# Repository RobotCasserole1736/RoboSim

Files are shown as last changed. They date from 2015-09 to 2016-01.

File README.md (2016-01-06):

# RoboSim
Arduino-based hardware-in-the-loop simulation of FRC robot hardware.

## Purpose
RoboSim is a set of hardware and software designed to enable simulation of 
mechanical hardware on a robot designed for the First Robotics Competition. 
The goal is to enable mentors and students to design a sufficiently functional plant mode for their robot, 
connect a fully-constructed electrical board with software, and observe the effects of control inputs on 
their simulated robot platform. This allows the electrical, software, and mechanical teams to work more in parallel.

## High level design.
RoboSim is build around an Arduino Mega. There are two sets of peripheral boards which 
expand the arduino's IO capability. The Arduino sends state information to a desktop PC 
running a plant model, and receives return data which it can feed back to the simulated 
robot's electrical board. The plant model on the PC is run using GNU Octave (a free Malab 
alternative). The Octave Plant model simulates the robot hardware (taking only motor and 
solenoid voltages as inputs). Serial data is transfered between the arduino and Octave for 
IO with the electrical board.

## Project Status
RoboSim is currently in development. All releases as of now are tested, but considered "alpha". 

## Screen-shots
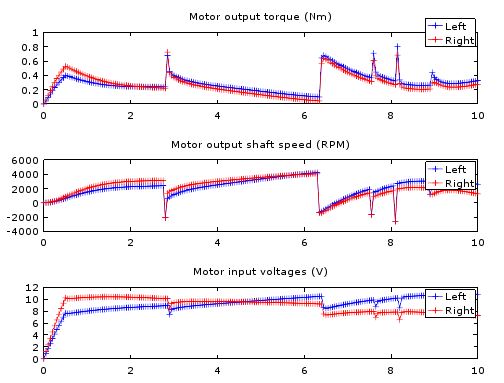
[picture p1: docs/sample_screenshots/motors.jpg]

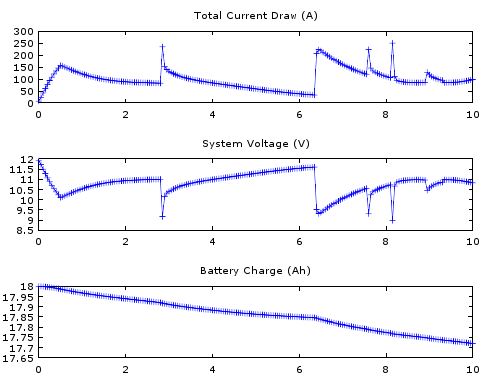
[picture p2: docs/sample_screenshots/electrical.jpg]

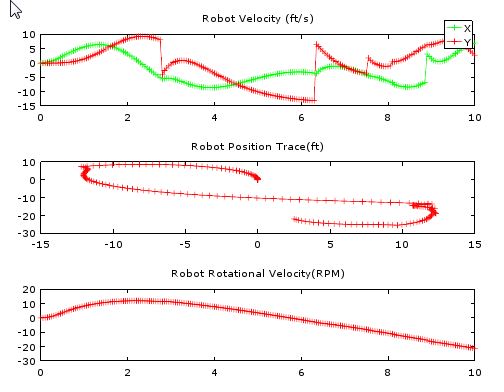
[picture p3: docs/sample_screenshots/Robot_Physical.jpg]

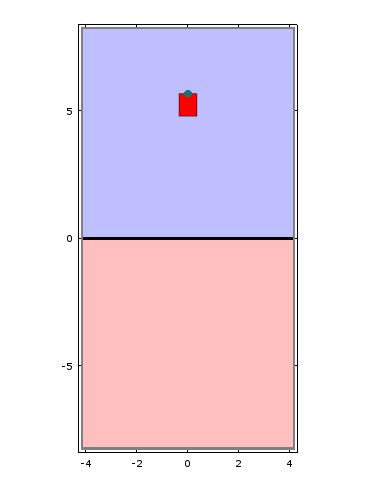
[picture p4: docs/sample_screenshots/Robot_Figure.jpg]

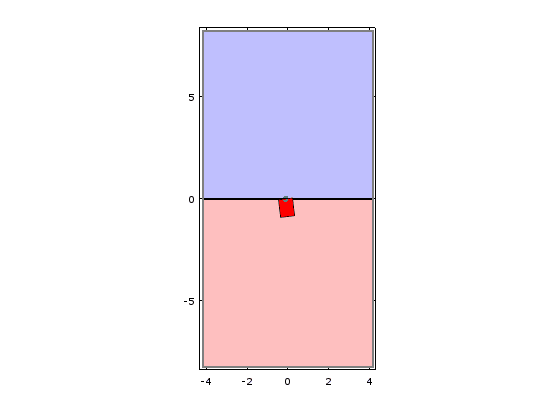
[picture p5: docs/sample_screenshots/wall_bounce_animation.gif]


## Repository Contents
- arduino_src - source code for the embedded arduino controller inside of RoboSim
- Octave - source code for the Octave-run plant model and GUI
- Eagle - electrical schematics for RoboSim peripheral boards
- PSPICE - electrical simulations for RoboSim peripheral boards
- docs - an increasing collection of documentation.

## Required software:
- Arduino IDE
  - https://www.arduino.cc/en/Main/Software
- Python 3.2 (32bit)- other versions may work but are untested
  - https://www.python.org/download/releases/3.2.5/
- PySerial 2.7 win32 py3k
  -https://pypi.python.org/pypi/pyserial
- GNU Octave + instrument-control package
  - http://www.gnu.org/software/octave/download.html
  - Once installed, run "pkg install -forge instrument-control" at the Octave command window
- Other Tools
  - Eagle PCB design
    - http://www.cadsoftusa.com/download-eagle/
  - LtSpice circuit simulator
    - http://www.linear.com/designtools/software/
  - Autodesk Inventor

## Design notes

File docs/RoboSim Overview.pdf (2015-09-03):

# RoboSim

### FRC Team 1736 Robot Casserole

## Overview

### - What:

- A flexible platform to simulate FRC robot hardware components
- A tool to increase development speed, test coverage, code and electrical robustness
- A platform for teaching concepts such as Plant Models, Design-For-Test, C coding, Digital Logic, Analog-Digital conversion, low-level embedded coding.

## Overview

### - Why

- Historically, electrical and software validation has been slowed due to lack of hardware to use for test ■ Mistakes can also be costly as mechanical components are damaged by errors in SW or wiring.
■ Mass permutation and regression testing is not feasible
■ Importance of testing has not been addressed.

## Overview

### - How

- Core real-time plant model running on Arduino Uno ■ Modularized SW for stable HW interface code with easy-to-modify plant model
- Visualization through connected PC
■ Python-based GUI
- Custom-built interface electronics to replicate CIM motors, encoders, analog sensors, limit switches, etc.

## Design Philosophy

### - Simulate Motors, Mechanical linkages & mechanisms, and sensor feedback only

- Input is voltage from motor controllers, output is simulated response of sensors and visualization
- Agnostic to electronics hardware technology
- Zero intrusion into electrical or SW design
- 100% of SW which impacts control can be tested

## Software Technologies Involved

### - Arduino

- Embedded C & C++

### - Python - Git

### - Future potential for Matlab/Simulink or Dynasty integration

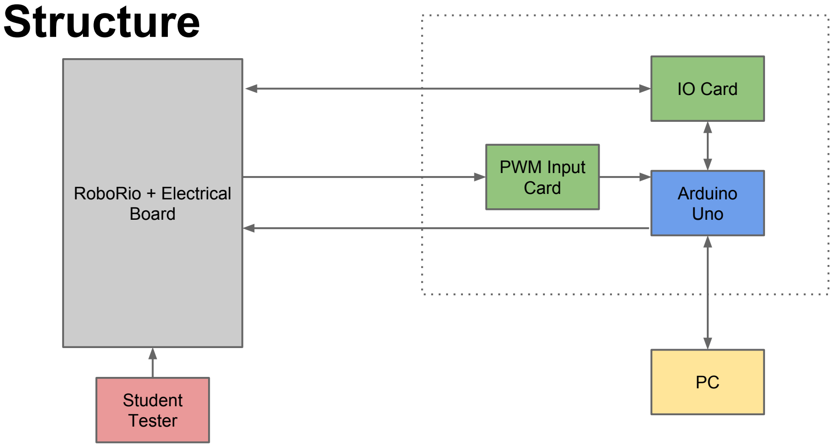
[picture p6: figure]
Structure; Arduino Uno; PWM Input Card; IO Card; RoboRio + Electrical Board; Student Tester

## Initial Spec for IO Capabilities

- 6 Motor Inputs (analog)
- Filtered by PWM Card, read by Arduino
- 8 Solenoid Inputs (digital)
- Read by IO card
- 8 Limit Switch Outputs (digital)
- Produced by IO Card
- 2 Analog Sensor Outputs
- R-R2 ladder DAC on IO Card, 0-5V
- 4 Quadrature Encoder Outputs
- Emulated in SW by Arduino

## Initial Spec for SW Capabilities

- 100ms Main plant model loop
- Processor load metric generated
- Serial port broadcast of state
- User defined update rate and message contents
- Interrupt-based emulation of Encoders onboard
- Isolated HW interfacing and Plant model code
- Plant custom to year, while HW interfacing stays constant

## IO Board

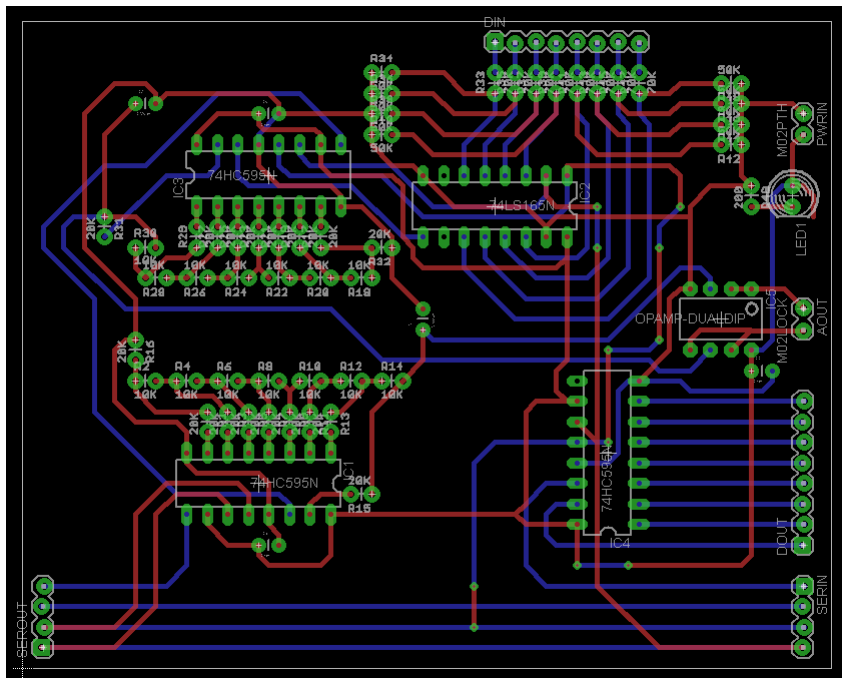
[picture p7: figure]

## IO Board - Description

### - Eight Digital Inputs - Eight Digital Outputs - Two Analog Outputs - Serial/Clock/Sync interface with Arduino - Can stack an arbitrary number of boards to increase IO

## PWM Input Card

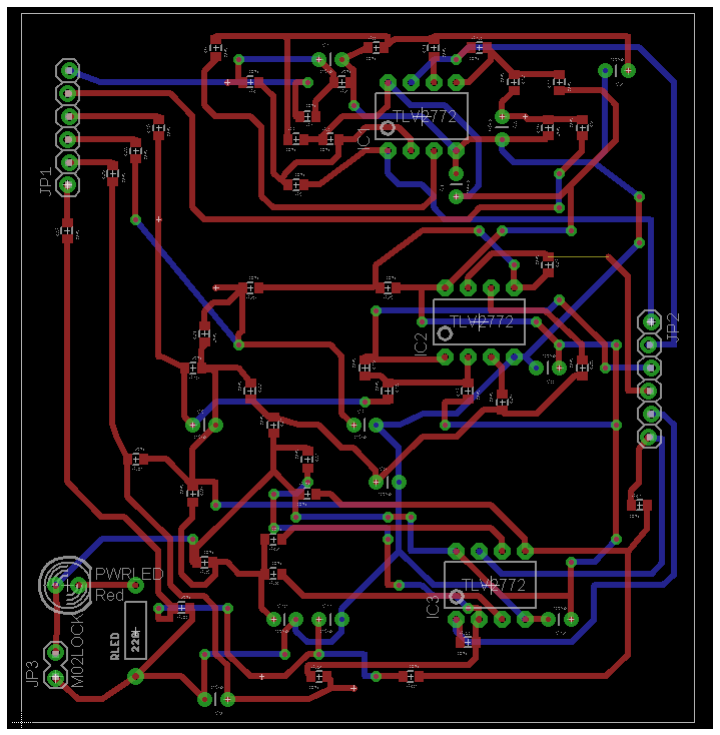
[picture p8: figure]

## PWM Input Card - Description

### - Six Low-Pass Filter and Offset Units - Converts PWM output from any Motor Controller into 0-5V signal readable by Arduino Analog Inputs - One card for Arduino Uno

## PWM Input Card - pSpice Simulation

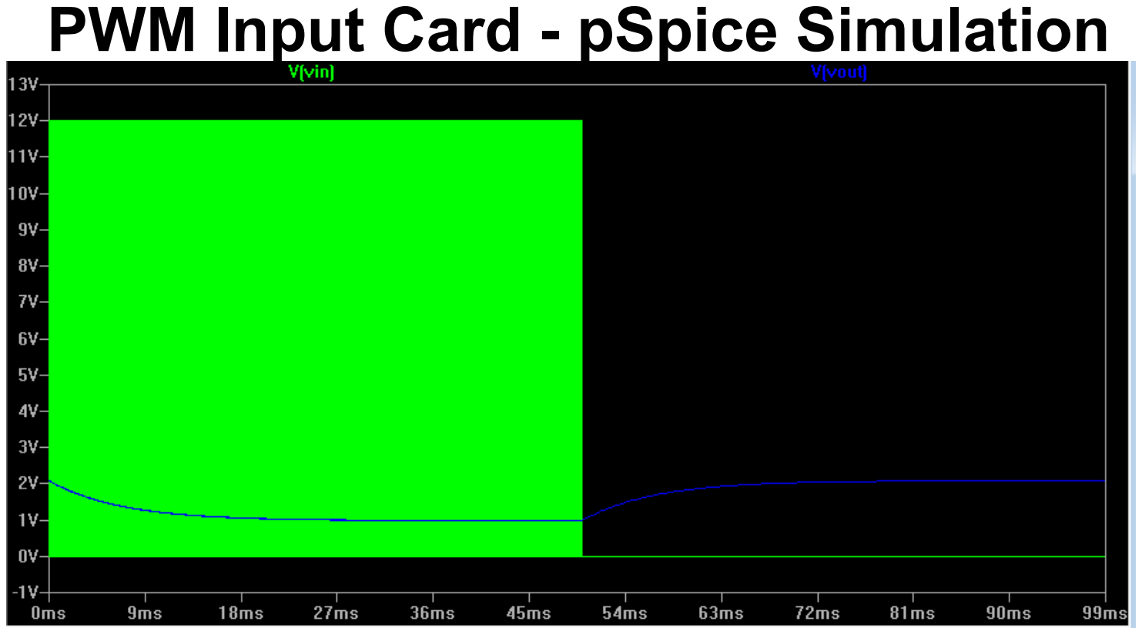
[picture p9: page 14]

## PWM Input Card - pSpice Simulation

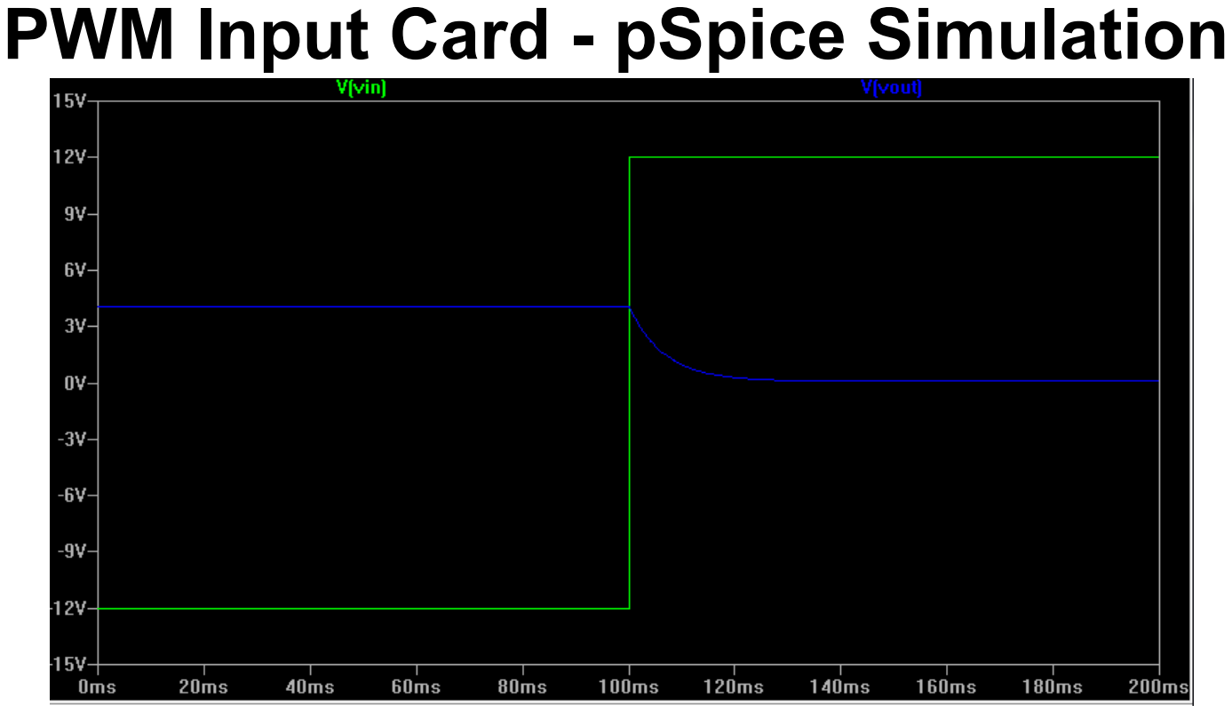
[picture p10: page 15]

## Quadrature Encoder Emulation

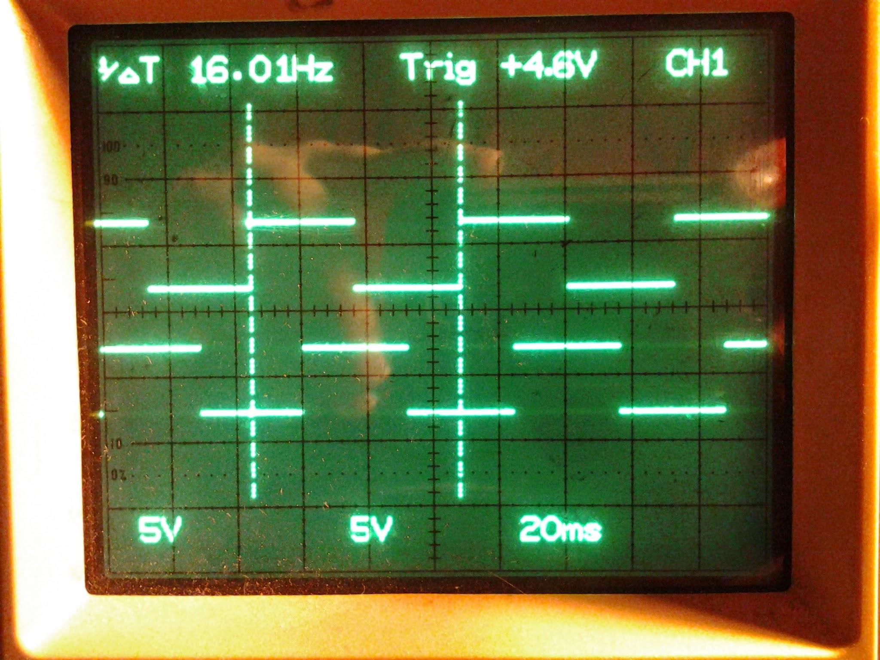
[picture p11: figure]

## Initial Cost Estimates

### - Arduino Uno - $30.00 New

- Can use existing

### - 1 IO Card + 1 PWM Card = $58.68

- No spare parts included in cost
- Can possibly source some parts from Cat B-Stock

## Community

### - Prototype source code is already available

- https://github.com/RobotCasserole1736/RoboSim

### - All designs will be open source

- Software (Arduino and PC)
- Hardware (Schematics, BOM, PCB designs)
- Documentation

## Future Expandability

- Design and validate plant models in Matlab, run generated code on Arduino
- Use larger Arduino with more Analog or Digital IO
- Controllable electronic loads to simulate motors in various operating conditions
- GPIB control of power supply to simulate battery voltage fluctuation with load
- Hardware-based Encoder Emulation
- More-robust electrical fault protection
- Automated regression testing routines

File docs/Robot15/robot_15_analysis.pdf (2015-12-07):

# RoboSim Sample Robot Plant Model Calculations

Chris Gerth - FRC 1736 Robot Casserole

Fall 2015

Abstract

An analysis of a simple tank-drive robot is presented. The simple plant model is designed to be a starting point for year-to-year development of more detailed robot models. The device modeled has two sets of motors to drive motion in a tank-drive fashion, along with a normal battery and electrical system.

## Contents

I | Background Academics Primer | 4
1 Calculus | 4
2 Trigonometry | 7
3 Physics | 7
II | Component Models | 14
4 Electric Motor | 14
5 Main Battery | 17
6 Main Circuit Breaker | 18
7 Compressor and Tank | 18
8 Traction Wheel | 19
III | Integrated Model | 20
9 Electrical Subsystem | 20

10 Drivetrain Subsystem | 20
11 Pneumatic subsystem | 23
12 Field Collision Model | 23
IV | Design Notes | 24
13 Software Architecture | 24
14 RoboSim Hardware | 26

## Part I

# Background Academics Primer

In this section, we will seek to demonstrate the “basic” math and physics required to understand RoboSim. This content is effectively a whirlwind summary of the important parts of AP Calc BC, AP Physics C, basic Chemistry, and any introductory Electronics course.

## 1 Calculus

Sir Isaac Newton was a smart man. He came up with calculus. Either him or Leibniz. In any event. Calculus is a particular field of study within mathematics. It studies functions and properties of functions.

### 1.1 Functions

A function can be thought of as a box which takes one input, and produces some outputs based on that input. For RoboSim, we will deal with many functions of time. This is to say that we will look at how properties change over time. The “Box” in this case is the robot itself. The most fundamental input to the robot is time. As time progresses forward, different properties of the robot change. These properties include things like location, speed, torque, rotation, electrical current draw, etc. In a mathematical sense, time is the input, and the various properties are the output. At every given time, each property has a value. Additionally, the physics of the configuration of the parts of the robot determine relationships between the quantities as time progresses forward. For example, a large voltage applied to motors will induce larger torques and speeds and current draws.

### 1.2 Continuous Functions, Derivatives and Integrals

Continuous calculus is what is usually studied in High School. It is assumed that time is linear and continuous. Valid times are t = 0s, t = 1.2429543987s, t = 3.25s, etc. Any value of time is a defined. An infinitely detailed timeline can be established.
Calculus looks at two primary things about functions: Derivatives and Integrals.
A Derivative of a function describes how quickly the function is changing as time goes on. On a curve on a Cartesian (x/y) plot, the derivative is the same as the slope of the curve at any given point, as shown in Figure 1.

x = y(t)

x =

dy
dt
An Integral of a function describes how big or small the function’s value has been historically. On a Cartesian plot, the integral is the same as the area between the curve and the x axis over a given period of time, as shown in Figure 2.

x = y(t)

X =

ˆ
y(t)dt + c

For the purposes of RoboSim, there is no need to discuss the calculation of integrals or derivatives in the continuous domain.
If a function is getting larger quickly, its derivative will be big at that time. If it is getting smaller in a hurry, its derivative will be negative
If a function has been big for a long time, its integral will be large. If it’s been bouncing around but equally above and below zero, the integral will be very small.

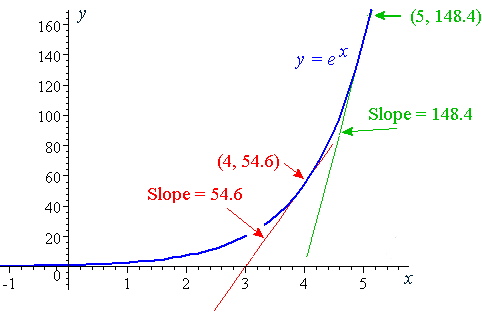
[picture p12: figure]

Figure 1: Illustration of a derivative as the “instantaneous slope” of a curve

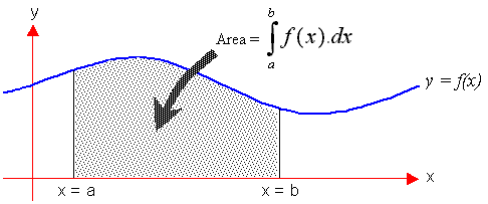
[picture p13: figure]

Figure 2: Illustration of a integral as the “area under a curve”

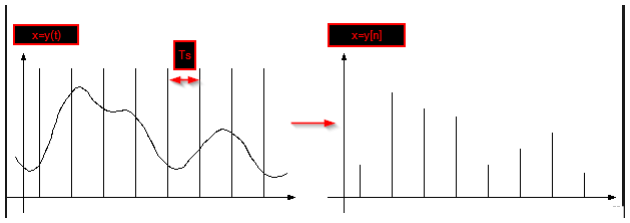
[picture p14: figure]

Figure 3: Sampling a continuous function x=y(t) to produce discrete function x=y[n]

### 1.3 Discrete Functions, Derivatives and Integrals

Discrete functions are very similar to normal functions, except they are only defined at certain, regularly-repeating time values. In this way, a discrete function could be though of as a set of time, value pairs.

{0.00, 3}, {0.01, 2}, {0.02, 1}, {0.03, 0}, ...

We might turn a continuous function into a discrete one by sampling it at regular intervals. This is usually the way that sensors and digital systems are integrated - the sensor reads an analog value continuously, and the digital system records the sensor’s value at specific points in time.
We usually notate a discrete time function as such

x = y[n]

For a function y that produces a value x at time index n. For all discrete functions, we must always specify a “Sample Time” (notated T s) to indicate the spacing between samples. For RoboSim, T s is hard-coded to 50ms. Note the square brackets which indicate discrete time. Here n is an index, not a measure in seconds. Multiplying the n index by the sample time T s yields the actual (real-world) time in seconds.
In Discrete time calculus, we define derivatives as follows:

x = y[n]

dx
dt

∼=

y[n] − y[n − 1]
T s
This formula says “A function’s derivative is equal to the current value minus the previous value, scaled by the sample time.” You may recognize this form from part of the “Limit” definition of a derivative. Note here that if we force Ts to zero, we have a continuous derivative. However, because computer systems cannot sample infinitely fast, we accept a small but finite Ts as a very close approximation. The conditions under which this approximation is acceptable is the subject of Nyquist Frequency theory, but is a topic out of scope for this discussion.
In Discrete time calculus, we define Integrals as follows:

x = y[n]
ˆ
xdt ∼=

Xn

i=0

y[i] ∗ T s

This equation says “A function’s integral is equal to the sum of all previous values, scaled by the sample time”.You may recognize this from the Riemann sum approximation of an integral. If we force Ts to zero, we end up with a continuous integral. But again, since computer systems cannot sample infinitely fast, we accept a small but finite Ts and move on with our lives.

## 2 Trigonometry

You are likely already aware of most trig concepts. sin(), cos(), tan()are among some of the functions you should be familiar with. For the purposes of calculations of robosim, we will do all angle calculations in radians. Additionally, we will use to atan2() function, which is very similar to the inverse tangent (atan()). However, it has some extra definitions to give it a full output range of [0, 2π]for any given X/Y inputs. You can look up more details online, but the formal definition is as follows:

atan2(X, Y ) =

atan −Y
X
X > 0
180◦ + atan
Y
X
Y ≥ 0, X < 0
−180◦ + atan
Y
X
Y < 0, X < 0
90◦ | Y > 0, X = 0
−90◦ | Y < 0, X = 0
undef ined | Y = 0, X = 0

## 3 Physics

Physics is also a thing that Newton did. Told you he was smart. In this section, we will begin to analyze the constraints imposed by mother nature between different quantities on our robot.

### 3.1 Position, Linear Motion, and Calculus

For physics to work, we must have objects in places. The place the object is at is called its Position. Let us define the following function which describes an object’s location along one axis at any time. Specifically, it says how far the object is from an arbitrary zero point at any time:

Distance = x[n]
Velocity is how fast an object is moving. Velocity can be positive or negative. Positive velocity means the distance gets bigger, and negative velocity means the distance gets smaller. Because of physics, velocity is therefore the derivative of distance.
V elocity = v[n]

v[n] = dx
dt =

x[n] − x[n − 1]
T s
Acceleration is how fast an object is changing in velocity. Acceleration can be positive or negative. A positive acceleration means the object is going faster and faster and faster. A negative acceleration means the object is slowing down. Because physics is still physics, acceleration is the derivative of velocity.

Acceleration = a[n]

a[n] = dv
dt =

v[n] − v[n − 1]
T s
Note that integration allows you to go the other way. That is to say, velocity is the integral of acceleration, and distance is the integral of velocity.

v[n] =Xn

i=0

a[i] ∗ T s

x[n] =Xn

i=0

v[i] ∗ T s

Plots of these relationships are shown in Figure 4.
For units, we will always use metric. Therefore, distance is in meters (m), velocity is in meters per second (m/s), and acceleration is in meters per second, per second (m/sˆ2)

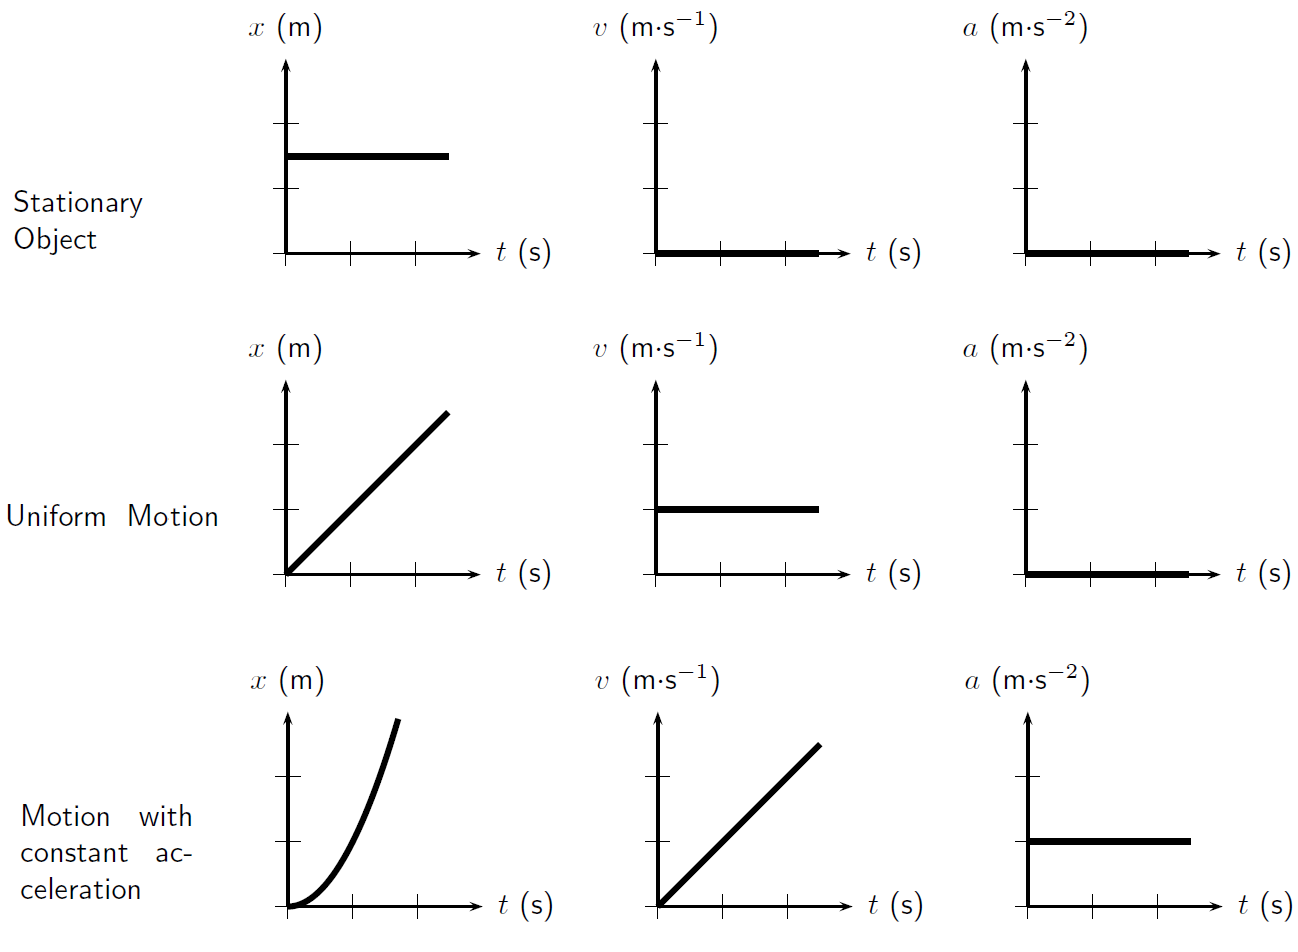
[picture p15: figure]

Figure 4: Examples of motion, relating acceleration, velocity, and position

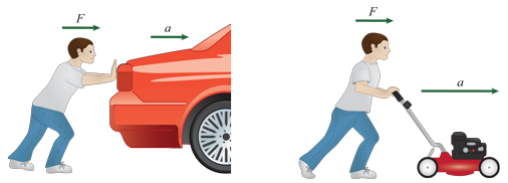
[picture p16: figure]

Figure 5: Newton’s Second Law

### 3.2 Forces and Linear motion

### 3.2.1 Newton’s Law

Force is something pushing on another thing. The more you push, the faster and faster you will go. The larger the object, the harder it is to make it go faster.
Newton’s laws of motion allow us to define the following: At any given time, Acceleration is proportional to Force, scaled by an objects mass:

F orce = mass ∗ acceleration

F[n] = m ∗ a[n]

Note that Force is measured in Newtons (N), mass is measured in kilograms (kg), and acceleration is in meters per second per second (m/sˆ2).
Note also that force changes over time, and acceleration changes over time, but we assume mass is constant.

### 3.2.2 Sources of Forces

Forces come from many places. A student pushing on a robot frame is one possible, simple source. A turning wheel in contact with the floor is another. Meshed gear teeth pushing on one another is yet another transfer of force. Of the list mentioned so far, friction is very important and has some special calculations associated with it.

### 3.2.3 Frictional Forces

Friction is a force which opposes two contacting surfaces from sliding relative to each other. It comes from microscopic interactions of matter in contact with each other. It can get very complex and is not fully understood, but can be well modeled at a macro level. We will discuss this model, as it is the most useful for FRC robotics applications. There are two main types of friction: Static and Kinetic.

### 3.2.4 Static Friction

Static friction deals with the case where two surfaces are not moving relative to one another. If you were to pin a book in place on a wall by only pressing on the book toward the wall, you would be using the static friction between the book and the wall to oppose the force of gravity, keeping the book from falling. This is illustrated in Figure 6. Static frictional force will take on whatever value it needs to to counter out other forces, up to a certain point. This certain point is called the maximum static frictional force. It is calculated with the following formula:

FSmax[n] = µS ∗ FN [n]

Here, FSmax is the maximum static frictional force. It always points in the opposite direction as any force acting along the same axis. FN is the “normal” force, or the force pinning the two surfaces together. µS is the Coefficient of Static Friction, which is derived from how effective the two surfaces are at sticking to each-other. Two smooth,

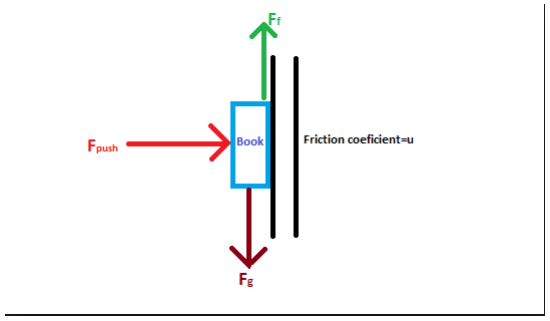
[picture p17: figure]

Figure 6: Static friction pinning a book to a wall

slick surfaces (like two pieces of smooth hard plastic) will have a small µS, while two rough surfaces (like concrete) will have a large µS. Usually, µS is just looked up in a table.
Static friction is often informally called “Stiction” in the engineering world, since it causes things to stick together. Also, “Stiction” is a portmanteau of “Static Friction”. Engineers are a clever bunch.

### 3.2.5 Kinetic Friction

Kinetic friction deals with the case where two surfaces are sliding relative to each other. If you were to slide a book along the ground, the force that opposes your efforts to push the book is the kinetic frictional force of the book in contact with the ground. It is calculated by this formula:

FK[n] = µK ∗ FN [n]

Again, FKis the kinetic frictional force. It always points in the opposite direction of motion of the interface (opposes the motion occurring). FN is still the “normal” force, or the force pinning the two surfaces together. µK is the coefficient of kinetic friction, which again determines how effective the materials can interface with each other to produce an opposing force.
For most materials, µK is slightly than µS.
Note that as a wheel is rotating with the ground, there is no relative motion between the ground and the point of contact with the wheel. Indeed, the motion of the robot is due to the rotation of the wheel, and not due to the wheel slipping over the ground. A non-slipping robot’s wheel-ground interface lies in the Static Friction domain. When wheel-ground interfaces start to enter the Kinetic friction domain, the effect is what many young people refer to as “drifting”.

### 3.3 Torque and Rotation

Because symmetry is a thing of life, Newton’s laws of motion also have analogs for rotational motion.
Instead of force, we now have Torque. Torque is force that goes in a circle. It is measured in Newton-meters. All torque acts about a central pivot point. This may be the center of mass of the robot, the center of a gear, the center of a shaft, the center of a wheel, etc.
As indicated by the unit, a torque always has two important things to consider - How much force is pushing in a circle, and how far from the center of the circle is that force acting?
The distance from the central pivot point of the rotation to the point of application of force is called the “Lever Arm” of the torque. Bigger lever arms mean more torque for the same force.
This is why wrenches have long handles. They are designed to turn things in a circle with some amount of torque. Assuming a human can only exert a maximum amount of force, a longer handle makes for a longer lever arm, which in turn means a higher max torque applied. If a bolt is stuck, one option is a bigger wrench with a longer handle.

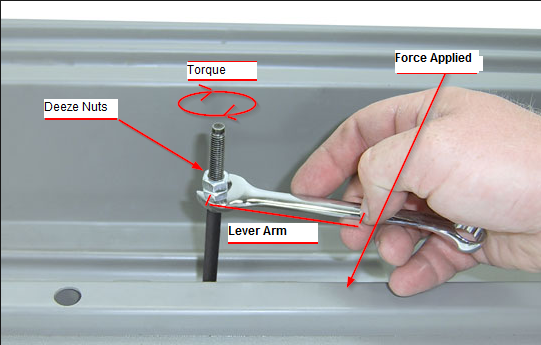
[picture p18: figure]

Figure 7: Torque exerted on a nut

### 3.3.1 Rotational Motion Parameters

There are rotational measurements which are analogous to the linear motion parameters discussed above. Lower-case Greek letters are used to describe these rotational parameters
The current angle a rotating object is pointed in is referred to as theta:

Angle = θ[n]

The rate at which that angle is changing is rotational velocity, or omega:

RotationalV elocity = ω[n]

The rate of change of the rotational velocity is the rotational acceleration, or alpha:

RotationalAcceleration = α[n]

As with linear motion, velocity is the derivative of position, and acceleration is the derivative of velocity.

ω[n] = dθ
dt =

θ[n] − θ[n − 1]
T s

α[n] = dω
dt =

ω[n] − ω[n − 1]
T s
Also as with linear motion, velocity is the integral of acceleration, and position is the integral of velocity.

ω[n] =Xn

i=0

α[i] ∗ T s

θ[n] =Xn

i=0

ω[i] ∗ T s

### 3.3.2 Torque and Rotational motion

The relationship between torque and rotational motion is highly analogous to force and linear motion:
At any given time, an object’s rotational acceleration is proportional to the torque applied to it, scaled by the object’s “moment of inertia”.

torque = moment of inertia ∗ rotational acceleration

T[n] = I ∗ α[n]

An object’s “moment of inertia” is like its total mass, but also accounts for how far that mass is from the center of rotation. The more mass an object has, and the further that mass is from the center of rotation, the harder it is to get the object rotating at a different speed. The actual value of this is in units of kilogram meters-squared (kg mˆ2), and is most easily calculated with a table of shapes and corresponding formulas.
Although we have assumed the moment of inertia to be constant, that is not always the case. Although it is rare for a robot to add or loose mass during a match, it is more common for the location of that mass to change on the robot. For example, if an arm extends out by a foot from the robot, the location of the mass of that arm is now further from the center. This increases the robot’s moment of inertia, which makes it harder for the drive-train to start or stop the robot from spinning.

### 3.4 Ideal Gas Law

Cylinders, tanks, compressors, and valves are all pneumatic components used on FRC robots. Pneumatic components on a robot all deal with the movement of compressed air, and the transfer of energy involved therein. Air is the gas used within these systems. Under the normal temperatures experienced in the robot, and the 125psi pressure restriction of FRC rules, air acts much like an ideal gas. Therefore, it is appropriate to model it with the ideal gas law:

P V = nrT

Here, P refers to the pressure of the gas (in kilo-pascals, or kPa), V refers to the volume of gas considered (in Liters, or L), T refers to the temperature of the gas (in kelvin, or K), and n refers to the number of moles of gas molecules being considered. The remaining symbol r is the “Gas Constant”, a constant with units L*kPa/(K*mol), and is numerically equal to 8.3144621. It is determined by the physics of interacting gas particles. Its derivation will not be described in this paper
Note also that n is in moles. A “mole” is a unit-less multiplier, like “dozen”. For example, if I have a dozen donuts, it means I have twelve donuts. Similarly, if I have a mole of donuts, I have 6.022 ∗ 10²³donuts. 1 The reason for its use here is that gas molecules are tiny, and usually we have a lot of them. It’s a lot simpler to do math talking about “1 mole of molecules” rather than absurdly large numbers.
What the ideal gas law describes is the relationship between pressure, temperature, amount of gas, the volume the gas occupies. For example, when a compressor kicks on, it forces more moles of air into the same volume. We also assume that temperature does not change. Therefore, based on the above equation, if T, r, and V are unchanged, and n increases, then P must also increase to keep the equation balanced. This makes since, since anyone who was observed a properly-set-up pneumatic system knows turning on the compressor makes system pressure go up.

### 3.5 Electrical Laws

Motors, motor controllers, batteries, wires, and circuit breakers are all part of the electrical system on a robot. These components obey many laws related to electricity.

### 3.5.1 Electrical Introduction

For FRC robotics purposes, electricity is the movement of electrons through “conductors”. A conductor is any substance which has freely-moving charged particles, most commonly electrons. Usually these movements are random, but when they start to go in the same direction, we say there is an “electric current” present. Metals are the most common conductors.
The opposite of a conductor is an insulator. Common insulators include glass, wood, and plastic. These substances to not have freely-moving charged particles, so they cannot sustain an electric current. By wrapping a

1

Interestingly enough, the average jelly donuts contains 10⁶ Joules of energy. This means that one mole of jelly donuts would have about 6 ∗ 10²⁹Joules of energy. The rotational energy stored in Earth’s rotation is about 2 ∗ 10²⁹Joules. This means that if you had a 100% efficient rocket powered by jelly donuts, and attached it to the earth’s equator, you could stop the earth from spinning, and still have 2/3rds of your donuts left over for eating! The more you know...

conductor inside an insulator, you create an isolated conduit to move electrical current in an organized fashion (eg, a wire).

### 3.5.2 Basic Electrical Quantities and Relationships

When talking about the flow of electrons, there are two important quantities.
Current is the number of electrons flowing past a given point over a given time. It is usually indicated by the lower-case letter i (blame the French). Units are almost always in “Amperes” or “Amps” for short. The Amp unit is denoted “A”. One amp of current is equal to 6.24 ∗ 10¹⁸electrons passing a given point on a wire in one second.

Current = i[n]

Voltage is the “force” which causes the motion of electrons in a conductor. The more voltage, the more of a punch the electrons will have. It is measured in a unit called “Volts” and denoted with the letter “V”.

V oltage = v[n]

Note that the word “force” is used very loosely here, as the energy associated with electricity has much more to do with electric and magnetic fields, and not so much the physical impact of tiny electrons on a mass. However, the details of this theory is beyond the scope of this paper.
Resistance is how easily a substance allows electricity to pass through. Conductors have a very low resistance, while insulators have a very high resistance. Resistance to electrical flow can be affected by many factors, including the temperature and physical shape of the device. Resistance is measured in a unit called an “Ohm”, and is denoted with a capital Greek letter Omega (Ω).
The resistance of a device determines how much voltage it pushes back with (ie, the “voltage drop”) when a current runs through it. This relationship is linear, and is expressed with Ohm’s Law:

v[n] = R ∗ i[n]

This equation states that for a given amount of current running through a device, that device will push back on that flow with a proportional amount of voltage, scaled by the device’s resistance.
For example, Ohm’s law explains why system voltage drops when you drive a robot very hard. All batteries have some small amount of internal resistance (something like 0.012Ω). They usually supply around 12V of voltage. However, as motors and solenoids and compressors draw large amounts of current, the battery internally starts to fight itself due to its internal resistance. The voltage actually supplied by the battery is then some quantity less than 12V, and the amount of drop is roughly proportional to the amount of current pulled from the battery. Inductance and Capacitance are properties of devices, describing their ability to store electrical energy and release it over time. The math associated with these is beyond the scope of this paper.
Power is not specifically an electrical topic, but relates strongly to electrical quantities. Electrical Power refers to the total energy absorbed or dissipated by an electrical component over time. Positive power in an electrical component implies energy is leaving the system (via motion, heat, sound, etc.), while negative power means energy is entering the system (Battery, power supply, hand-cranked generator, etc.)
Power is calculated in many ways. In general, it can be found my multiplying voltage and current:

P[n] = v[n] ∗ i[n]

Power will be measured in units of Watts (denoted “W”).

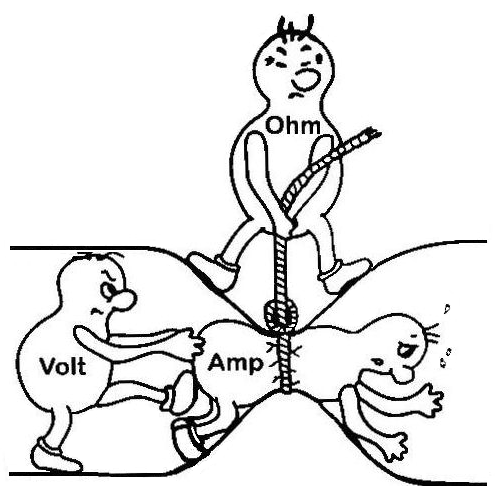
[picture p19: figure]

Figure 8: Ohm’s Law, with various electrical quantities models as anthropomorphic peanuts.

## Part II

# Component Models

## 4 Electric Motor

Simply put, an electric motor is a device which converts electrical energy into rotational mechanical energy. Current flowing through the motor causes a force on the motor. However, the interactions of the motor’s electrical and mechanical parts also drives a variety of equilibrium points. Due to the level of interaction, an electric motor is one of the more complex devices to model. It helps to split the motor into two portions, the electrical and the mechanical parts.

### 4.1 Electrical Model

A motor, electrically speaking, is a two-terminal device. For a DC motor,its interior windings and communicator will be modeled as a resistor, inductor, and voltage source in series. The resistance and inductance model the physical configuration of the windings inside the motor. The wire itself is always non-deal, having some resistance. Additionally, since the wire is wrapped in tight coils, there is some non-negligible inductance.
The voltage source models what is referred to as “Back EMF”. Remember that a changing magnetic field inside coils of wire will induce a voltage in those wires (this is how electrical generators work). Although at first it is the energy input to the motor that causes the shaft to start to spin, as the shaft spins it generates its own set of magnetic fields. This secondary field begins to induce a new voltage in the coils called Back EMF. This voltage’s value is linearly proportional to the speed the motor is turning at. This is why a free-wheeling motor has a maximum speed.
All these parts of the electrical model create voltages to oppose or aid the flow of current through the motor. At the end of the day, the torque produced by the motor is linearly proportional to the current flowing through

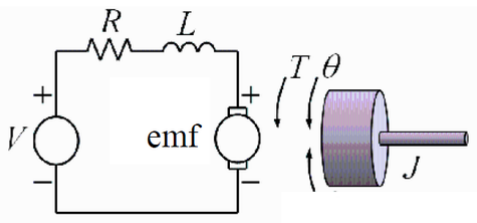
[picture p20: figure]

Figure 9: A combined motor electrical and mechanical model

it.
To illustrate, follow this example concerning a free-wheeling motor (no load torque): The motor is stopped, and a voltage is suddenly applied to it. Little current flows at first due to the inductance. However, as time goes on, the magnetic field builds up and more and more current flows. As current begins to flow in ever increasing quantities, more and more torque is applied to the output shaft. The output shaft begins to accelerate due to the torque. As the output shaft picks up speed, the back EMF voltage also increases. Soon, it is no longer the inductance that is limiting current flow, but instead the back EMF voltage source. Eventually, an equilibrium is hit where there is (theoretically) no current flow through the motor anymore, as the back EMF voltage completely counters out the supply voltage.
In reality, there is always a small current draw due to the load torques from friction in the internal bearings (and various other reasons).
Given a supply voltage and a back EMF, applying KVL around the motor circuit in Figure 9, we deduce the following continuous-time equation for the motor current:

Vin(t) = Im(t)Rm + Lm

dIm
dt + Vemf (t)

Here, Vinis the supply voltage to the motor, Rmand Lm are the motor’s winding’s resistance and inductance (in Ohms and Henries), and Vemf is the Back EMF voltage from any rotation of the output shaft. The Lm

dIm
dt term
comes from the voltage-current relationship in an inductor. Simply put, an inductor produces a large voltage in response to large changes in current (hence, the derivative term). The derivation of this relationship is beyond the scope of this document.
Moving to the discrete domain, we find the following equation:

Vin[n] = Im[n]Rm + Lm

Im[n] − Im[n − 1]
T s |
+ Vemf [n]

We now solve for Im[n], the motor current at the present time-step:

Im[n] = 1
Rm +

Lm
T s
LmIm[n − 1]
T s

− Vemf [n] + Vin[n]

### 4.2 Joining of Electrical and Mechanical Models

Now, we shall introduce some constants to link the mechanical and electrical models together.²
These can be derived from analyzing the physical construction of the motor, but are usually empirically measured. The Torque Constant Kt determines the relationship between Torque and Current. We define the following linking equation:

2Data for this section can be found in the CIM motor curves available from Andymark: http://files.andymark.com/CIM-motor-curve-am-0255.pdf

Tm[n] = Kt ∗ Im[n]

Tmis the torque produced on the output shaft of the motor.Kt is measured in units of Torque per Current, or Nm/A
It is known that at zero current, zero torque is present (hence, no need for any constant offset in the above equation). Kt is most easily calculated from a motor’s Stall Torque and Stall Current, two figures readily available for most motors.

Kt =

Tstall

Istall
In the case of a CIM motor, the stall torque is 2.429 Nm, and the stall current is 131.227 A.
The Speed Constant Kidetermines the relationship between the magnitude of the Back EMF voltage, and the rotational speed of the output shaft. We define the following linking equation:

Vemf [n] = Ki ∗ ωm[n]

ωmis the rotational speed of the output shaft of the motor. Ki

is measured in units of Voltage per Rotational Velocity, or V/(rad/s).
It is again known that at zero speed, there is zero back EMF. Ki

is most easily calculated by analyzing the motor in its “free-wheeling” speed, where a positive voltage Vsupply has been applied to the motor, and a maximum speed has been observed sustained at the output shaft (ωFW ). Assuming the input current in this state (IFW ) is also known, the following relationship is true:

Ki =

Vsupply − IFW ∗ Rm

ωFW
Be sure to add scaling constants for units as needed - Current is often reported in mA (not A), and free-wheel speeds in RPM (not rad/s).
Substituting these Electrical/Mechanical constant relationships in and re-arranging terms, we arrive at the final equation used in the motor model:

Tm[n] = Tm[n − 1] + Ts ∗

Kt
Lm
Vin[n] −

Tm[n − 1]Rm
Kt

− Ki ∗ ωm[n − 1]

Im[n] = Tm[n]
Kt
We have now reduced the motor to a model which takes a voltage, speed, and previous torque as input, and determines what the new torque value should be. Additionally, via the second equation, we can determine the current draw of the given motor.

### 4.3 Integration with Larger Systems

The one remaining relationship unexplored is the speed-torque relationship in the motor. Thus far we have defined the motor which produces some torque, dependent upon the voltage applied and the speed the motor runs at. However, once this torque is applied, how quickly does the speed change? This question can only be answered by analyzing what the motor is hooked up to. In the case of a free-wheeling motor, not attached to anything, the answer lies in the moment of inertia of the shaft itself, and the rotational friction in the bearings. When driving an actual robot, the torque of the motor is transferred through the drive-train to the ground. The wheels convert the torque to a linear force, and start rotating in response to the net acceleration of the robot. This rotational speed is then transferred back up through the drive-train to the motors. In all cases, friction provides a constant drag on motion. The exact math in determining the torque-speed relationship must be derived from the device attached to the motor, not the motor itself.

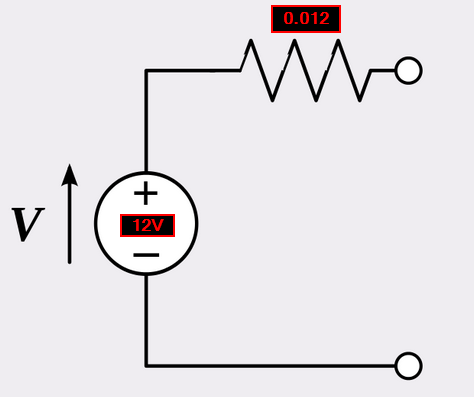
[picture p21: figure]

Figure 10: A non-idea voltage source, modeling a battery

## 5 Main Battery

There are many sources of power for electrical circuits. While analyzing circuits, the most common source used is what is referred to as a “Ideal Voltage Source”. This is a device which produces a voltage across its terminals, and that voltage does not change with the amount of current flowing through the device. In theory, such a device could provide an infinite amount of power (keep voltage the same as current increases indefinitely). This assumption makes analysis of circuits easier, but fails to provide the whole picture.

### 5.1 Modeling Voltage Drop due to Instantaneous Current Draw

A battery is what is referred to as a “Non-ideal Voltage Source”. It can be modeled with an ideal voltage source in series with a resistor. The voltage source models the current-pushing potential of the chemical reaction in the battery, and the resistor models the internal parasitic resistance which causes voltage to drop as more current is drawn. The MK ES17-12 batteries standard for FRC³ have an average internal resistance of 0.012Ω. The nominal (no-current-draw) voltage of the battery can be anywhere from 13V down to 8V or even lower, depending on how much the battery is charged.
For the purposes of RoboSim, we have not yet modeled the decaying nominal voltage of the battery as it discharges, since the simulation is not designed to be accurate for long-term endurance tests. However, we have modeled the drop in supply voltage with elevated current draw. See Figure 10 for the circuit model employed. In general, the output of the battery model is the system voltage, and the input is the total current draw from the battery. The model is governed by the following equation:

Vsys[n] = Vnom[n] − Rbat ∗ Idraw[n]

Vsysis the robot system voltage at a given sample time n. Vnom[n]is the nominal (no-current-draw) voltage of the battery. For simplicity it may be assumed to be 12V, but could also be calculated based on the remaining charge in the battery. Rbatis the parasitic internal resistance of the battery, assumed equals to 0.012Ω for the ES17-12. Finally, Idrawis the total current demand of the robot at sample time n. Within the plant model, the total current draw is calculated by summing the current draw from each motor, solenoid, compressor, etc., along with nominal background current draw (such as electronics, lights, or fans).

3Constants derived from data-sheet at http://www.mkbattery.com/images/ES17-12.pdf

### 5.2 Modeling Total Remaining Charge based on Aggregate Current Draw

Additionally, the battery model usesIdrawto calculate the total charge remaining in the battery. This charge-remaining metric could be used to drop nominal battery voltage over time, but will also give developers indication of the amount of battery life drained by performing certain maneuvers with their robot. The battery is designed to have 17 Amp-Hours of charge in it. This means that you can pull 17 amps for one hour, one amp for 17 hours, or any other combination of amps and hours which, when multiplied, gets you to 17. We model battery charge by calculating the number of Amp-Hours drained from the battery by the current draw every plant loop. This behavior is defined by the equation:

Q[n] = Q[n − 1] −

Idraw[n] ∗ T s
3600
Q[n] is the present charge (in amp-hours) in the battery, and Q[n−1] is what the charge was last loop. Here, we always calculate the present charge by subtracting the current draw (in amps), multiplied by the sample time (with a 3600 factor to convert Ts from seconds to hours). This charge metric can be used to analyze expected battery life of a given robot design.

## 6 Main Circuit Breaker

## 7 Compressor and Tank

The compressor and tank library model reporesent the source of pneumatic energy for the robot. The compressor modeled is the Viair 90C, standard for FRC robots. The air tanks have an adjustable volume (set by defining the number of half-liter tanks).

7.1 “The System”

For all pneumatic calculations, the volume inside the tanks, tubing, valves, etc. is modeled collectively as the “system”. In principle, there are a certain number of air molecules inside of this system at all time. The model track the number of moles of air inside the system, and then can calculate the pressure using the total volume and an assumed temperature. The compressor as a device adds moles of air to this system, while any leaks or cylinder actuations reduce the number of moles in the system.
The system requires a “reset” trigger at the start of the simulation. When reset, it triggers calculations to determine nominal (ie, one-atmosphere) quantities of air molecules in the system. This initalizes the state variable to the right number of moles of air for an assumed temperature.
The temperature of air in the system is assumed to always be at 70◦F. This is based on the idea that the compressor does not induce much extra heat into the air it compresses, and any extra heat is dissapated to the atmosphere through the compressor metal body, tank walls, and tubing. Making this assumption allows us to not have to calculate the thermal equations relating heat loss through a complex system of many different materials of different shapes.

### 7.2 Compressor

Viair provides performance data for its compressors. For the 90C model, there is a non-linear relationship between flow rate, pressure, and drawn current. At any given time, the compressor must fight the system pressure to put more air into the system. Additionally, the faster the flow rate and the higher the system pressure, the more current is needed to keep pushing moles of air into the system. The numerical values can be found in the compressor’s datasheet, and are plotted with interpolation in Figure 11.
Note that the performance data is listed in imperial units, so some conversion factors are applied in software to get to the metric equivilants.
Every simulation loop, a total number of new moles of air to be added to the system is calculated based on this performance data, and whether the compressor is running or not. By using the ideal gas law, and assuming the system pressure is known, the number of new moles of air can be calculated:

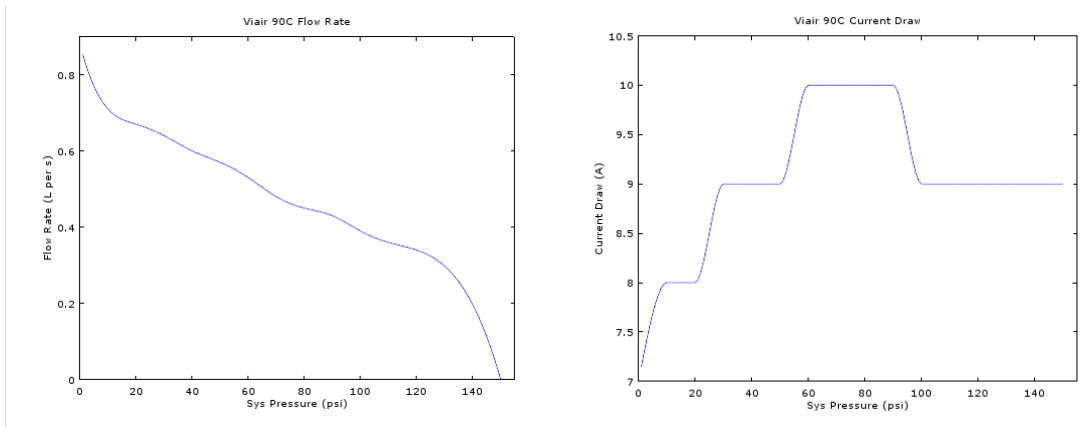
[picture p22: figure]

Figure 11: Viair 90C Performance Data

4num moles comp[n] = P[n − 1]F[n] ∗ T s rT
For P being the previous system pressure, F being the volumetric flow rate (calculated from performance data if compressor is running, or 0 if not running),T s being the sample time, T being the system air temperature (assumed equal to70◦F), and r = 8.31 being the gas constant in units of L∗kP a
K∗mol.
Finally, given the current system pressure and running/not-running state of the compressor, the current draw at timestep n may also be calculated.

## 8 Traction Wheel

## Part III

# Integrated Model

There are multiple parts to the robot model. Each shall be discussed in detail here.

## 9 Electrical Subsystem

The electrical subsytem consists of the robot’s power source (the main battery), all current drawing devices (motors, solenoids, compressors, etc.), and any safety devices (main circut breaker, etc.).
One of the key metrics to track is total current draw from the battery. As soon as we know the compressor state and motor torques, we calculate total current draw with the following equation:

Idraw[n] = (IMR[n] + IML[n]) ∗ NM + Icomp[n] + Inom

Here, IMLand IMRare the current draw from the left and right motor respectively. Icompis the air compressor current, which is assumed 0 until the pneumatic system is implemented. Finally, Inomrepresents background, nominal current draw from the roboRIO, LED’s, fans, etc. We have modeled it as a constan 0.5A current draw. System voltage is the voltage supplied by the battery to all of the robot components. Usually it is near 12V, but large current draws or weak batteries may decrease it. This Idrawis used to calculate the present system voltage via the equations laid out in section 5. Additionally, the main battery charge is tracked via the equation presesnted in that same section. Idrawis also used by the main circuit breaker model to determine if the breaker should be in a tripped or closed state. If tripped, system voltage is driven to zero. See section 6 for more details on this component.
Once the system voltage is known, it can be used to calculate adjusted motor voltages driving the motors. There is feedback here: as motors push harder, they draw more current, which drops the system voltage. In turn, this prevents the motors from outputting their maximum power. This systsem-voltage-drop relationship is maintained by treating the voltage input waveform (whether from the RoboSim hardware measurements or from test vectors in a fully-simulated setup) as “voltage commands”. The actual voltage going to each motor is calculated off of this equation

VM[n] = Vsys[n]
12

∗ Vcmd[n]

Where Vcmdis the commanded voltage to the motor, Vsysis the robot system voltage, and VMis the voltage actually applied to the motor.

## 10 Drivetrain Subsystem

The drivetriain consists of the components which exert forces on the net robot body, and move it around the field. Conceptually, it transforms torque from the motors, and calculates what forces those torques exert on the robot. Then, an acceleration, velocity, and position of the robot body can be calculated from these forces. Rotation is also accounted for. Finally, the net motion of the robot is transformed back into a speed, which is fed back up through the drivetrain to determine what rotational speed the motors are running at.
For Robot 15, a simple tank drive is modeled. The Drivetrain consists of two sets of drive wheels/motors/gearboxes
- a left and a right set. Each set of drive equpment has a given gear ratio, wheel diameter, and number of drive motors. It is assumed that each drive equipment set can exert a force toward the front or the back of the robot, and that force is applied at a point offset to the leftt or right of the robot’s physical center. The distance from the center to the point of force application is called the “Motor Width”
The robot additionally has a width and height (the half-width and half-height are shown, and are used in the software for calculations). The X and Y axes are also provided. Note that all linear velocity components are assumed relative to reference frame fixed on the field, not on the robot (unless otherwise indicated)
The first step in the calcualtions for the drivetrain are to calculate all the forces acting on the robot.

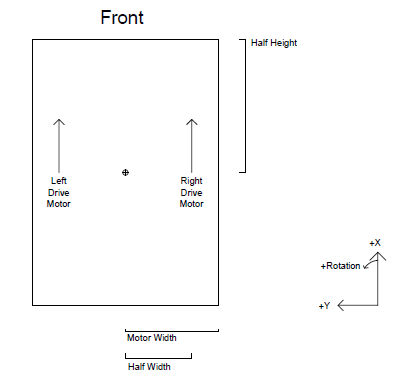
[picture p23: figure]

Figure 12: The model of the tank drive robot. Note that MotorWidth and HalfWidth are mixed up, this should be changed.

### 10.1 Linear Force from Drivetrain Motors

The torque from the motor is a function of the motor’s speed and the supply voltage. See section 4 for the derivation of torque from speed and supply voltage. Given the left and right motor torques, a linear force magnititude on the robot can be calculated:

Flin[n] = (TL[n] + TR[n]) ∗ NM DW ∗ R

For TLand TRbeing the torque (in Nm) produced by the left and right motors respectively, NMbeing the the number of motors powering each side of the drivetrain (usually 2 or 3), DW being the wheel diameter (in m), and R being the gear ratio of the gearboxes and any sprokets used. Note that R might actually change over time if shifting gearboxes are used.

### 10.2 Net Rotational Torque from Drivetrain Motors

Next, because the forces from each side of the drivetrain act at a non-zero difference from the center of mass of the robot, they may exert a net torque on the robot. This is what allows the robot to rotate in place. The magnititude of this torque on the robot is calculated:

Tnet[n] = (−TL[n] + TR[n]) ∗ NM ∗ Wmot DW ∗ R
All variables used here are the same as above, with the addition of the motor width, Wmotin meters.

### 10.3 Wheel friction

Wheel friction is currently under development. So far, we will only calculate kinetic friction which opposes the robot from sliding side-to-side (perpendicular to the direction the drive wheels point). Note this force is large for traction wheels, but very small for omni-wheels. By adjusting the coeficent of friction in the robot configuration structure, different types of wheels can be tested.
The first step is determining what component of the robot’s velocity is perpendicular to the direction the wheels are pointed

∆θ[n] = atan2

Vy[n]
Vx[n]
− θrobot[n]

Vperp[n] = q
Vx[n]

2 + Vy[n]

2 ∗ sin (∆θ[n])

For Vy and Vxbeing the y and x components of the robot’s current velocity, and θrobotbeing the current direction the robot is pointed in.
Then, using the equations for kinetic friction described in section 3.2.5, we can determine a magnititude for the frictional force from the wheel opposing side-to-side motion:

Ff ric,perp[n] = −Vperp[n] ∗ Kk,wheel

For Kk,wheelbeing the net kinetic coefficent of friction for all wheels in contact with the ground.

### 10.4 Induced Motion

We now have all forces requried to calculate the net motion of the robot from the drivetrain. We will use the relationship force equals mass times acceleration, solved for acceleration. We will consider the X and Y components separately. We must use trig to determine the net X/Y motion based on the direction the robot is pointed, which in turn dictates which direction the drivetrain can push or apply friction in.
The acceleration in the X and Y directions (WRT a fixed reference frame of the field) for the robot is:

Ax[n] = Flin[n] ∗ cos (θrobot[n]) + Ff ric,perp[n] ∗ −sin (θrobot[n])

Mrobot

Ay[n] = Flin[n] ∗ sin (θrobot[n]) + Ff ric,perp[n] ∗ cos (θrobot[n])

Mrobot
For Mrobotbeing the robot’s mass in kg.
Additionally, we also calculate the rotational acceleration from the induced torque:

α[n] = Tnet[n]

Irobot
For Irobotbeing the robot’s net moment of inertia (like mass, but for spinning things). Not having any better ideas, we modeled the robot’s mass as being uniform throughout a subsection of its base. By making this mass-distributed-in-a-rectangular-prisim assumption, we can assume the following value for the moment of inertia:

Irobot =

Mrobot
12

∗

h
(0.9 ∗ Lrobot)

2 + (2 ∗ Wmotor)
2

i

For Mrobotbeing the robot mass in kg, Lrobotbeing the robot’s total length from front to back bumper, and Wmotorbeing the distance from the robot’s centerpoint to the point of force application of the drivetrain(in m). Now that we have the accelerations, we can use the physics equations determined in section 3.1 to deduce the robot’s current position, velocity, rotation, and rotational velocity.

### 10.5 Motor Speed Calculation

Finally, we must pass back up the robot’s net motion to calcualte the speed each motor is running at. This is crucial for determining accurate future torque values.
We must account for the robot’s current orientation on the field, it’s X and Y velocity, and its rotational velocity. For both motors, we calcualte speeds with the following equations.

ωL[n] = [Vx[n]cos (θrobot[n]) + Vy[n]sin (θrobot[n]) − ωrobot[n] ∗ Wmotor] ∗ 2π DW ∗ R

ωR[n] = [Vx[n]cos (θrobot[n]) + Vy[n]sin (θrobot[n]) + ωrobot[n] ∗ Wmotor] ∗ 2π DW ∗ R

The next control loop, these new speeds will be fed into the motor model to calculate the next torque.

## 11 Pneumatic subsystem

This has been paritally implemented, and not at all documented. To be updated....

## 12 Field Collision Model

The field collision model determines behavior when the robot collides with a wall of the field. The collisions are inelastic - that is to say, some of the energy is absorbed by the bumpers. This means the robot bounces back on a collision, but is traveling slower.
The field collision model is still very crude, and for that reason will not be described in depth. Suffice to say, the basic principe is that when the robot comes in contact with a wall, one part of the velocity (X direction or Y direction) is reversed and reduced to simulate a “bounce”. Future work will model this bounce more accurately, and also examine the rotational effects of a corner of the robot hitting the wall before the rest of the robot does.

## Part IV

# Design Notes

## 13 Software Architecture

The sim software architecture is desiged to be flexible and modular, with large parts that can be re-used year to year. Most “components”’ to the simulation will have an init (run once) and a main (run once per loop) file. We will briefly describe each file

### 13.1 sim main

Sim main.m is the main entry point for the simulation. This is the file to run in Octave when you wish to run a simulation. It calls all the initilization functions and runs the main control loop.
After clearing the Octave workspace, sim main will load the instrument control package (needed for serial communication with the RoboSim hardware), add additional folders to its path (so it knows where to find utility and library files), start up some logging, and then call additional initilization inside sim init.m. After that, a progress bar is displayed and a timer is started to ensure the perioidic loop is run at the correct rate.
The periodic loop will run for the number of timesteps specificed at sim initilization time.On each loop, the first thing done is to mark the time the loop started at. This will be used at the end to determine how long to wait to maintain a consistant run rate. Next, the inputs for this control loop are gathered via in proc.m. Then the robot plant model is run, and any robot/field physics calculations are run. Then, the results of this loop are set to outputs via out proc.m. Lastly, if it is desired to run this simulation in real-time, the simulation waits for a given amount of time to ensure a consistant loop run time (ie, sample rate).
Finally, after the simulation has completed the required number of main control loops, the post proc tasks are run. Then the simulation exits.

### 13.2 sim init

Sim init contains some of the simulation-enviroment-specific setup and data structures. Here, you can set the sample time (reccommend 50ms. Also, any changes here must have corresponding changes in the arduino software as well). You can also specify simTime, the length of time in seconds the sim will run for. There are two other important switches: one to decide if input comes from predefined simulation testcases or from RoboSim hardware (the use serial variable), and another to determine if the simulation should attempt to execute in real time (ie, each control loop is 50ms) or not (ie, each control loop runs as fast as possible). Running real-time is nice to get a good conceptual feel for how the robot will look as it moves around, and is required if use serial is 1. However, if plots of test results are of primary concern, you can set enforce realtime to 0 and get faster execution time.
After setting these variables, sim init runs initilization for the robot and for the field, then opens up the serial connection to the RoboSim hardware if hardware is being used.

### 13.3 robot init 15

Robo init is run once before the start of the main simulation loop. Its purposes is to initalize the internal state and configuration structutes of the robot, and draw the initial robot onto the field.
There are three main structures - config, state, and calc config. Config values will be constant throughout the simulation. They represent the physical properties of the robot (physical dimensions, weight, number of motors, number of air tanks, etc.). These physical paramaters are all used in the physics-based calculations of the robot’s actions. Note that the units of each parameter should be included into the comments associated with the params (units matter! And there’s little oppurtunity to figure them out from the rest of the code!). The state structure holds all the physical paramaters which change over time (acceleration, rotation, position, system voltage, etc.). Again, units should be specified. Since this is a digital system, it’s expected that some of the values will have “current” and “previous” values. At the end of each main loop, the structure should be considered to have all the data associated with the robot at timestep n. Finally, there is an additional structure for the calculated config values. These should not be edited from robot to robot - the values are derived from other config values. These are things like unit-converted values (ex: mass in kg) or the moment of inertia, which can be calculated from other known values.
After the structures for the robot have been defined, a few more are added for specific components. Currently, this is for the motors.
Finally, a few calculations are done to draw the initial robot onto the field. The initial figure is selected, and the robot square is drawn. Additionally, a small marker circle is drawn on the front of the robot to differentiate it from the back.

### 13.4 field init 15

Field init is responsible for setting up the field paramaters structure, and drawing the field. The field structure contains info about the physical dimensions of the field components, as well as various drawing paramaters. After the struct is initalized, a figure is created, the axis is set up to be used as a canvas to draw the field on, and the actual components of the field are drawn. This drawing needs only be done once, unless a field element is animated.

### 13.5 in proc

In proc is the input processing script. It is responsible for getting inputs from some source, and updating the input structure based on those inputs. The input structure is its own set of time-changing values, containing the current set of inputs (usually motor and solenoid voltages).
In general, if a serial port connection is used, the serial read packet function is called to get input from the arduino. On a bad packet being recieved, the old packet is maintained and a warning is printed to screen.
If no serial port is needed, the input structure is instead populated using some pre-defined time-voltage vectors. These vectors are defined within the in proc script itself. The define a voltage to set, and the time at which to set it. Between given points, linenar interpolation is used.
This “no-serial-port” mode allows robot designers to test different driving conditions with different physical parameters, with no electrical board built.

### 13.6 robot 15

The Robot 15 script executes the integrated model of the robot. No data structures are defined here - the robot state and outputs structures are updated based on the inputs, physical parameters, and previous state. See Part III for more information on the content of the robot 15 script.

### 13.7 field robot physics

The field robot physics script re-adjusts the robot state structure based on any interaction between the robot and the field. Usually, this interaction means the robot ran into a wall or a part of the field. See section 12 for more info on how collisions are handled.

### 13.8 out proc

The Output Processing script is designed to, well, process outputs. This means updating any animations based on the newly determined state of the robot, and recording values of importance. To limit memory usage, only specific signals are recorded over time - output processing is where a full time-based vector of imporptant values (ex: robot x and y position) is updated with the current value. For most values, only the current (and maybe the previous) value is kept in memory. But for signals which will be analyzed after the simulation is complete, a vector which has enough space to hold all values of the signal during the simualtion is updated.
Additonally, the verticies of the robot on the field are recalculated and re-set. A command is called to update the drawing on the screen.

### 13.9 post proc

After the simulation is completed, the recorded vectors must be plotted. These plots are generated with proper scaling and labeling in the post proc script. Additionally, if a serial port was used, it is shut down cleanly in this script.

## 14 RoboSim Hardware

To be completed.....

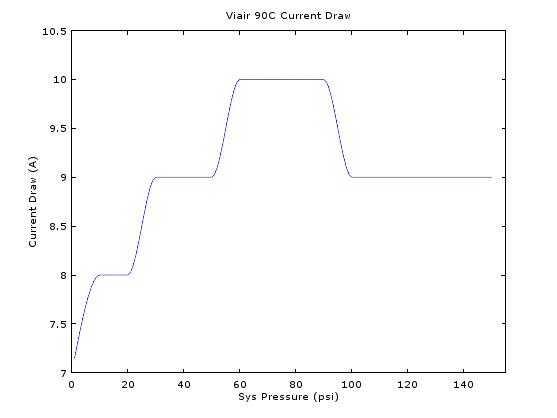
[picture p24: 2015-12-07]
docs/Robot15/resources/viair90C_current_draw.png

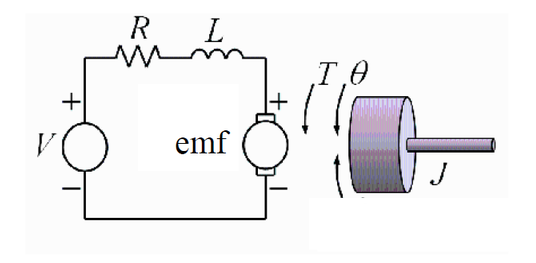
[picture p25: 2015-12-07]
docs/Robot15/resources/motor_mdl.png

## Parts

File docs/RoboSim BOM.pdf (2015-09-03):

Part | Link | Supplier | Subunit | Price/unit | Needed Num | Order Num | Cost | Total
74HC595N | http://www.digikey.com/product-detail/en/SN74HC | Digikey | IO Board | $0.62 | 3 | 3 | $1.86 | $58.76
74LS165N | http://www.digikey.com/product-detail/en/SN74HC | Digikey | IO Board | $0.52 | 1 | 1 | $0.52
0.1uF Cap | http://www.digikey.com/product-detail/en/K104K10 | Digikey | IO Board | $0.24 | 3 | 3 | $0.72
0.795 uF Cap | http://www.digikey.com/product-detail/en/FK28X5R | Digikey | IO Board | $0.23 | 2 | 3 | $0.69
20K Res | http://www.digikey.com/product-detail/en/MFR-25F | Digikey | IO Board & PW | $0.10 | 30 | 30 | $3.00
10K Res | http://www.digikey.com/product-detail/en/MFR-25F | Digikey | IO Board | $0.10 | 14 | 14 | $1.40
50K Res | http://www.digikey.com/product-detail/en/MFR-25F | Digikey | IO Board | $0.10 | 8 | 8 | $0.80
70K Res | http://www.digikey.com/product-detail/en/MFR-25F | Digikey | IO Board | $0.10 | 8 | 8 | $0.80
80K Res | http://www.digikey.com/product-detail/en/MFR-25F | Digikey | IO Board | $0.10 | 36 | 36 | $3.60
220 Res | http://www.digikey.com/product-detail/en/RNMF14 | Digikey | PWM Input | $0.14 | 1 | 1 | $0.14
200 Res | http://www.digikey.com/product-detail/en/MFR-25F | Digikey | IO Board | $0.10 | 1 | 1 | $0.10
R2R OpAmp | http://www.digikey.com/product-detail/en/TLV2772 | Digikey | IO Board & PW | $2.45 | 4 | 4 | $9.80
DIP Holder | http://www.digikey.com/product-detail/en/A08-LC-T | Digikey | IO Board & PW | $0.18 | 9 | 9 | $1.62
breakaway header | http://www.digikey.com/product-detail/en/PRPC02 | Digikey | IO Board & PW | $0.41 | 3 | 3 | $1.23
Red LEDs | Already Got them | Digikey | IO Board & PW | $0.00 | 2 | 2 | $0.00
100uF Cap | http://www.digikey.com/product-detail/en/TAP107K | Digikey | PWM Input | $2.03 | 6 | 6 | $12.18
0.5uF Cap | http://www.digikey.com/product-detail/en/C330C47 | Digikey | PWM Input | $0.94 | 6 | 6 | $5.64
Protoboard | http://www.digikey.com/product-detail/en/8015-1/V | Digikey | IO Board & PW | $7.33 | 2 | 2 | $14.66
| | | | | | | $0.00
| | | | | | | $0.00
| | | | | | | $0.00
| | | | | | | $0.00
| | | | | | | $0.00
| | | | | | | $0.00
| | | | | | | $0.00
| | | | | | | $0.00
| | | | | | | $0.00
| | | | | | | $0.00
| | | | | | | $0.00
| | | | | | | $0.00
| | | | | | | $0.00
| | | | | | | $0.00
| | | | | | | $0.00
| | | | | | | $0.00
| | | | | | | $0.00

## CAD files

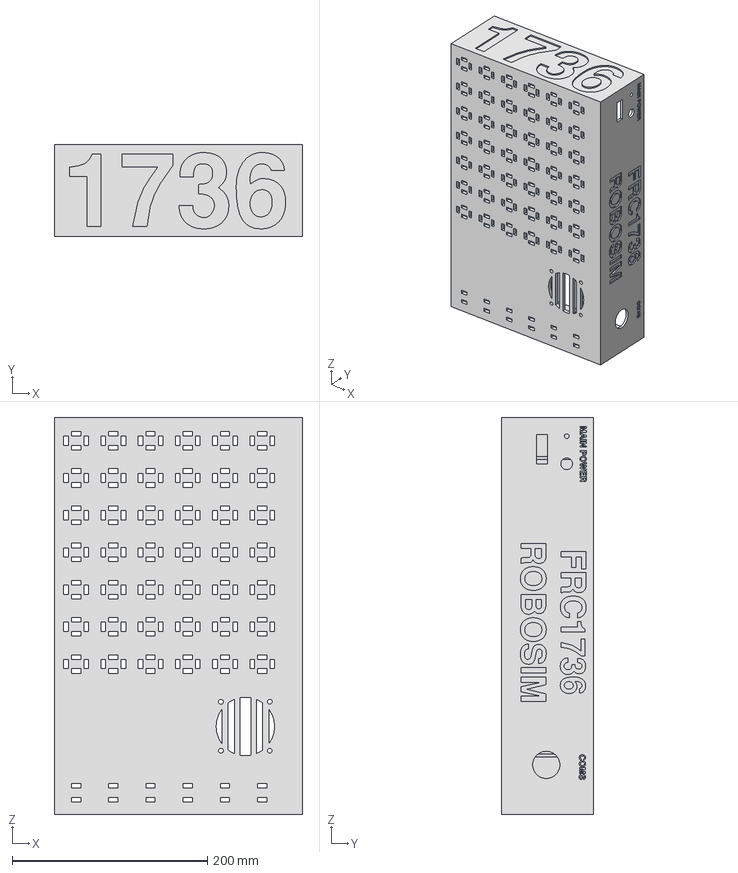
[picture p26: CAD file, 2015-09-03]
Enclosure/main_enclosure.stp
254.0 x 94.0 x 406.4 mm

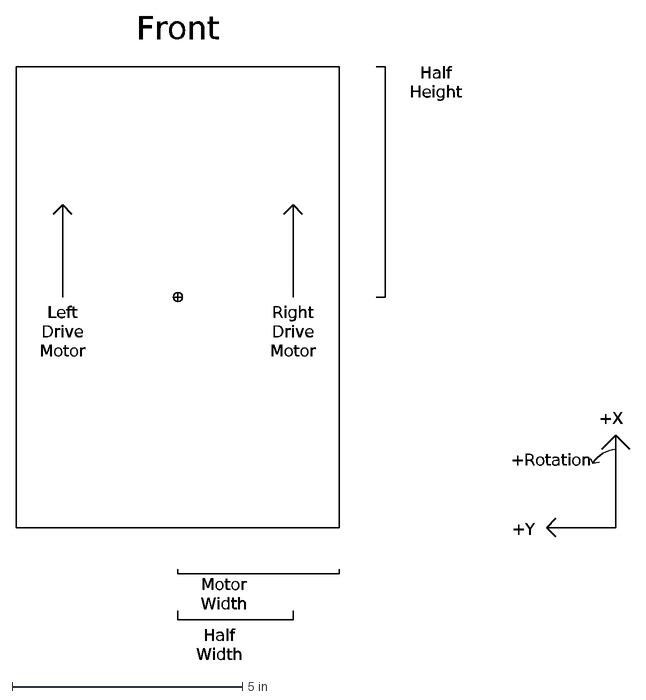
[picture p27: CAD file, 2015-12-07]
docs/Robot15/sim_model.dxf
Front
Left Drive Motor
Right Drive Motor
Motor Width
Half Width
Half Height
+X
+Y
+Rotation

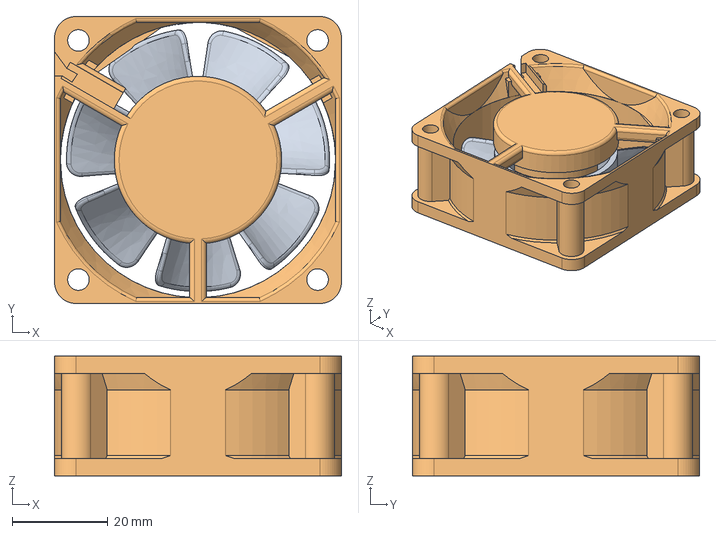
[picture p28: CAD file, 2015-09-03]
Enclosure/Fan 60x60x25mm.stp
60.0 x 60.0 x 25.0 mm

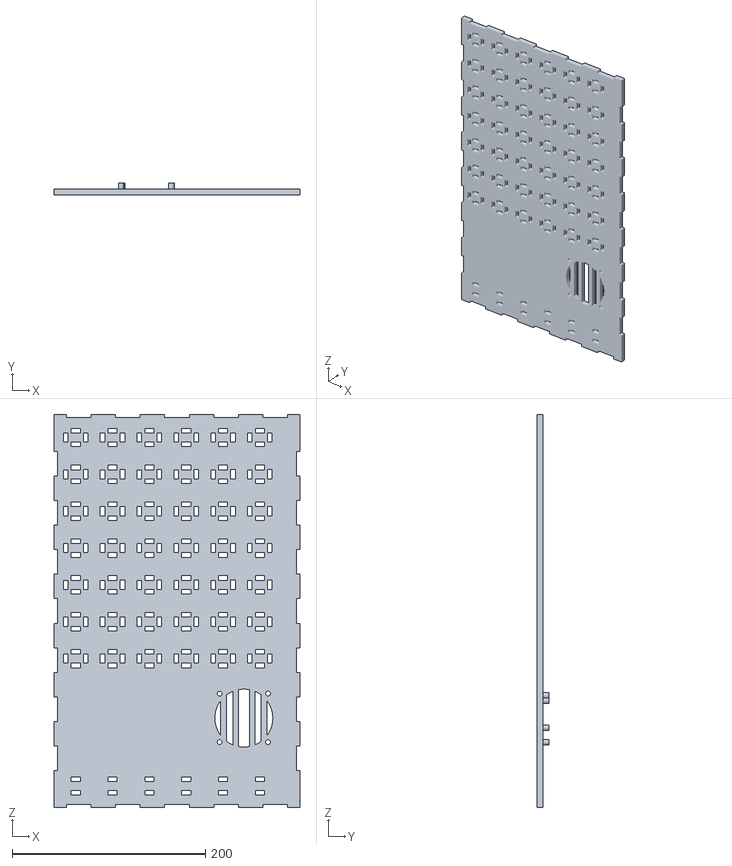
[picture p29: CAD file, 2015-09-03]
Enclosure_parts/base.stl
254.0 x 12.7 x 406.4

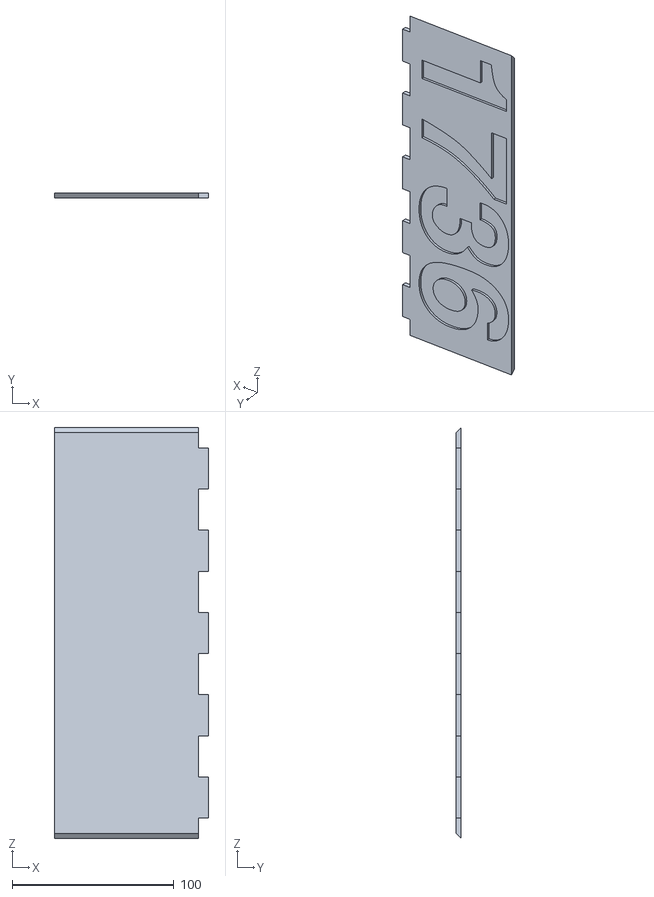
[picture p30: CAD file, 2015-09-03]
Enclosure_parts/side.stl
95.2 x 3.17 x 254.0

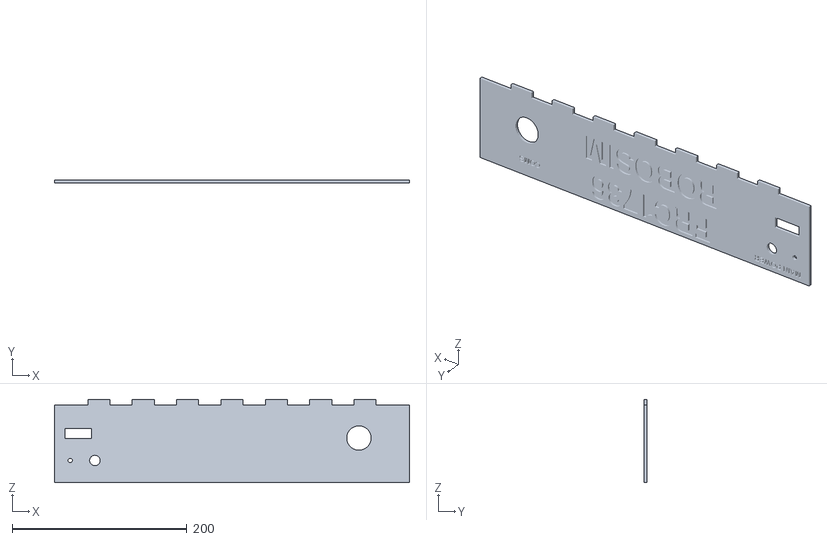
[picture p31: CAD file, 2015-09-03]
Enclosure_parts/front.stl
406.4 x 3.17 x 95.2

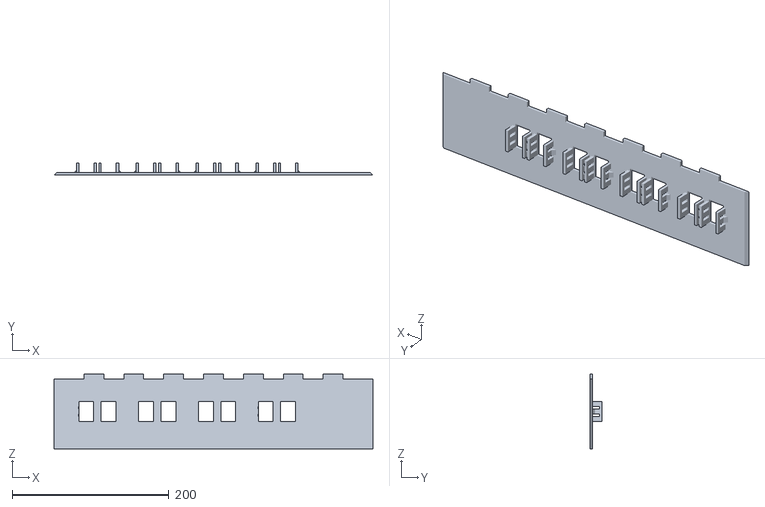
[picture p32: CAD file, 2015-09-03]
Enclosure_parts/rear.stl
406.4 x 15.9 x 95.2

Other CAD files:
Enclosure/10 PORT HEADER.ipt
Enclosure/102 RESISTOR PACK.ipt
Enclosure/103 RESISTOR PACK.ipt
Enclosure/16mhz crystal - measured.ipt
Enclosure/220 RESISTOR PACK.ipt
Enclosure/2pin_header__02.ipt
Enclosure/47uf CAP Dcase.ipt
Enclosure/6 PORT HEADER.ipt
Enclosure/603 cap on pad.ipt
Enclosure/603 resistor.ipt
Enclosure/8 PORT HEADER.ipt
Enclosure/ATMEL328P.ipt
Enclosure/Fan 60x60x25mm.iam
Enclosure/MLC0603.ipt
Enclosure/OldVersions/main_assembly.0001.iam
Enclosure/OldVersions/main_enclosure.0009.ipt
Enclosure/PADS001.ipt
Enclosure/RESET BUTTON.iam
Enclosure/RESET CORE.ipt
Enclosure/RESET.ipt
Enclosure/SW3dPS-fan 60x60x25 mm_Carcasa Ventilador 60x60.ipt
Enclosure/SW3dPS-fan 60x60x25 mm_Carcasa Ventilador 60x60_1.ipt
Enclosure/USB SHELL.ipt
Enclosure/USB core.ipt
Enclosure/USB type b.SLDPRT.iam
Enclosure/arduino uno.iam
Enclosure/atmega16u2.ipt
Enclosure/blm21.ipt
Enclosure/cd1206 diode.ipt
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

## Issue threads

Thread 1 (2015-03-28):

Create Basic Shift-Register IO Board

gerth2, 2015-03-28:
Create a board using three shift registers for IO.

Use Sparkfun's https://www.sparkfun.com/products/733

This board should handle:
8 Solenoid Inputs
--WIll need to have voltage divider and input level protection circutry to bring 0-12 signals to TTL levels
8 Digital Outputs
--5V logic level should suffice. Should have over-voltage protection circuitry

gerth2, 2015-10-07:
Completed and validated. PCB design exists, but final design was made by hand

Closed 2015-10-07.

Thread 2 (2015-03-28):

Create Analog Read interface code

gerth2, 2015-03-28:
Add code to interface with all six analog inputs.
Will need to set up pins and read them (two functions?)
Should map analaog bit values read to -1, 1 range with proper scaling/offset/flip

gerth2, 2015-10-07:
Scaling must return actual read voltage (-12V to 12V), not the arbitrary -1-1 range

gerth2, 2015-10-07:
Need 3-point map to properly scale/offset the read in voltage.

gerth2, 2015-11-02:
3-pt map has been implemented, need HW to fully test. Assumed working for now, will open new issue if not.

Closed 2015-11-02.

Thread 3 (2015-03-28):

Create motor model

gerth2, 2015-03-28:
Create real-time model of CIM motor.

Inputs and outputs are flexible. One possibility is input as Voltage and Torque (load), output is angular speed.

gerth2, 2015-10-07:
Sample model created. Long term need to convert to objects with methods

Closed 2015-10-07.

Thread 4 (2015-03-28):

Create Prototype Drivetrain

gerth2, 2015-03-28:
Create simple drivetrain. Should have two motors, configured for tank drive. Must have internal state variables for Robot X, Y position and pose angle. Internal state should be visualized.

All simple plant models will be made in Octave.

gerth2, 2015-11-02:
Basic structure has been created (much thanks to @gurellia53 for the help!). Will open more specific issues as need arises.

Closed 2015-11-02.

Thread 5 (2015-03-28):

Create Octave plant model and visualization

gerth2, 2015-03-28:
Creat simple Python GUI to read serial port text input, and generate a visual representation of the robot. Test with simple drivetrain example.

gerth2, 2015-10-07:
Visualtion will be done with Octave. Basic models are in process

gerth2, 2015-11-02:
Basic visualization completed. Will open new issues when more specific needs arise.

Closed 2015-11-02.

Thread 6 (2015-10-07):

"High Level Design" typos

Thuney, 2015-10-07:
-perripherial +peripheral

-capiability + capability

ruski550, 2015-10-07:
we'll look at it at lunch tomorrow, bed time

On Tue, Oct 6, 2015 at 10:04 PM, Aaron Thune <notifications@github.com>
wrote:

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

Thuney, 2015-10-07:
Was actually just to let Chris know he had typos in his documentation, nothing else.

gerth2, 2015-10-07:
Nah that's awesome, thanks guys! I know there's some,out of date info there
(like, we're using an arduino mega, not an uno). I'll try and update it
this week.
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

gerth2, 2015-10-07:
Do you guys have edit abilities on here? I should add you if not. Feel free to update as you see fit.

Thuney, 2015-10-07:
I don't think I have edit capabilities. It just gave me the option to fork
the repo. I'm going to start looking at the code to see what I can do to
help.
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

Closed 2016-01-14.

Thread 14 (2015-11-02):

Add test signal input architecture to plant model

gerth2, 2015-11-02:
For non-serial plant model execution, model inputs are currently just jammed into the sim_init.m file. Create a multi-testcase architecture for pre-defining a number of waveforms for inputs with meaningful testcase names. Dev should be able to easily switch between testcases

shivchaitanya, 2015-11-03:
Can I take up this activity if you don't mind?

gerth2, 2015-11-03:
All yours!

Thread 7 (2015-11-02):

Add compressor & tank library to simple drivetrain

gerth2, 2015-11-02:
Add a compressor and air tank to the test (robot_15) plant model. Leverage from the common models in lib.

Should be hooked into the electrical model (total current draw should increase while compressor is on).

For now, assume there is no exit for the air (no relief valve, no pneumatic cylinders, etc.). This will just be the start for when pneumatic-powered manipulators are added later.

gerth2, 2015-11-26:
Added to main model, cleaned up some generated files in the process. Sitting on a branch, will merge with next release

Closed 2015-11-26.

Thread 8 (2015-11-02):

Model wheel slip

gerth2, 2015-11-02:
Currently, the plant model assumes that the drive wheels never slip relative to the ground. (ie, coefficent of static friction between ground and wheels is infinite)

Update plant model to allow for wheel slip. Must model that some force is transferred during slip. Model behavior should be unchanged from current during no-slip conditions. Robot state should have two new variables indicating whether the left or right sides (or both) are slipping or not slipping (in kinetic or static coefficent of friction domains)

Add config values for static and kinetic coefficients of friction along the direction of wheel rotation. Assume we're using wheels like these: http://www.andymark.com/product-p/am-0438.htm (there may be more searching for datasheets required...)

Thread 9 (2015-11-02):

Improve wall collision model

gerth2, 2015-11-02:
Robot wall collision model is very crude now, and does not account for robot shape or rotation.

Update collision model to actually detect when any corner of the robot exceeds any field wall boundary. Apply the approprate collision mechanics to produce new x,  y, and rotational  acclerations/velocities/positions.

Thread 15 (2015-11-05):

Implement Stack Usage Monotoring

gerth2, 2015-11-05:
Each process in the RTOS uses a certain amt. of stack space, which varies at runtime with the depth of functions called. Motoring the peak stack usage is crucial to determining how many resources to allocate to each process, and predicting runtime errors from stack overflow.

Add functions and processes to do the following:
1) After processes are created but before they are started, "Paint" the allocated stack space for the process with a deterministic pattern of bits
2) At various points during runtime, walk each processes stack from top to bottom to determine the amount of "Undisturbed" stack left (assume that when a process actually uses stack space, it overwrites the deterministic pattern from step 1). The % stack usage is 100*(1-undisturbed_stack/total_stack)

Be sure to check for interactions with the RTOS's existing stack overflow checking functionality (especially method 2):

http://www.freertos.org/Stacks-and-stack-overflow-checking.html

This % usage calculation could likely just be an extension of method 2. Design is up to developer.

Print this info to a new page in the OLED display rotation.

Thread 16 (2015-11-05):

Implement process execution length

gerth2, 2015-11-05:
Add functions to instrument the length of time a task takes. The more detailed the better, but the instrumentation code should not severely degrade overall performance.

Some instrumentation already exists in the OS: http://www.freertos.org/rtos-run-time-stats.html . See about using this info and printing it to screen. The functions may not have all been implemented properly for arduino.

gerth2, 2015-11-05:
see also http://www.freertos.org/uxTaskGetSystemState.html and http://www.freertos.org/uxTaskGetSystemState.html#TaskStatus_t

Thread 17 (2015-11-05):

Evaluate faster sample rates

gerth2, 2015-11-05:
Up till now, RoboSim has been designed with a 100ms main loop sample time in mind. It is known the IO board can go way faster. It is desired to evaluate if this can be decreased any more. A test label exists for the start of this work (50ms sample time), but stability needs to be evaluated. It should also be checked if a faster plant model rate can be attempted, and interpolate with two loops per serial rx... Many options here...

gerth2, 2015-11-14:
Got down to 50ms as of release 0.14.0.DEV. We can evaluate lowering it further after some development has gone on, but I suspect this is good enough for now. Closing out the issue, can re-open if we find instability with the system.

Closed 2015-11-14.

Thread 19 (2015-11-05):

Create Installer utility for all required/optional tools

gerth2, 2015-11-05:
Add an installer for setting up a new pc for robosim.

Needed SW:

Octave, Arduino, Python, PySerial,

Optional SW:
Eagle, LtSpice, LyX, LibreCad

imdunne8, 2015-11-05:
Really simple with NSIS, and there's a great example here: http://nsis.sourceforge.net/Embedding_other_installers - Probably an easy one for a student to do some night

Thuney, 2015-11-05:
I'll see if I can get it done tonight.

On Nov 5, 2015 2:29 PM, "imdunne8" <notifications@github.com> wrote:
>
> Really simple with NSIS, and there's a great example here:
http://nsis.sourceforge.net/Embedding_other_installers - Probably an easy
one for a student to do some night
>
> —
> Reply to this email directly or view it on GitHub.

gerth2, 2015-11-05:
Actually if you don't mind, could we put one of the newer students on it? I
can have them ping you for help. I'm itching to get the onboard with things
other than practice problems. I've got the couple of other robosim code
activities out there as well.
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

gerth2, 2015-11-06:
Required SW:
https://www.arduino.cc/en/Main/Software (Arduino the main sw needed)
https://www.python.org/download/releases/3.2.5/ (Python, a tool used to help build arduino software. MUST USE THE 32 BIT VERSION!!!!)
https://pypi.python.org/pypi/pyserial (PySerial, a library needed to detect what port the arduino is connected to)
http://www.gnu.org/software/octave/download.html (Octave, the software for doing robot plant modeling and analysis)
--After completed, run the command "C:\Octave\Octave-4.0.0\octave.vbs --no-gui --persist  "pkg install -forge instrument-control"" (without the outside quotations)
--may need to adjust the install path per where the installer puts it.

Optional:
http://www.cadsoftusa.com/download-eagle/ (Eagle, a circuit design tool)
http://www.linear.com/designtools/software/ (LtSpice, a circuit analysis tool)
http://librecad.org/cms/home.html (free autocad sw for drawing diagrams)
ftp://ftp.lyx.org/pub/lyx/bin/2.1.4/LyX-2.1.4-Bundle-4.exe (Lyx, a document processor for LaTex)

gerth2, 2015-11-27:
I think we were able to finish this up. Was the final installer tested and uploaded anywhere? If not we should try on github large file hosting, maybe? There's other options too. We could make electrical test it out on one of their laptops too, since they'll probably want some of the SW anyway...

imdunne8, 2015-11-27:
We did divided this up but didn't upload it. I think Github LFS is worth
trying too, we just need to have a student download the actual Github
client. We didn't put any command line options on any of the installers, so
we could also potentially simplify some installs by making them silent.
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

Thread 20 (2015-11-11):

Model main circuit breaker

gerth2, 2015-11-11:
Add a library module for the main circuit breaker
module should accept a current value and input voltage, and supply an output voltage.

see http://files.andymark.com/PDFs/am-0282_data_sheet.pdf for a plot of the relationship between over-current and trip time

gerth2, 2015-11-11:
Library should also output a boolean to indicate a tripped or not-tripped state.

Once tripped, state may latch at tripped.

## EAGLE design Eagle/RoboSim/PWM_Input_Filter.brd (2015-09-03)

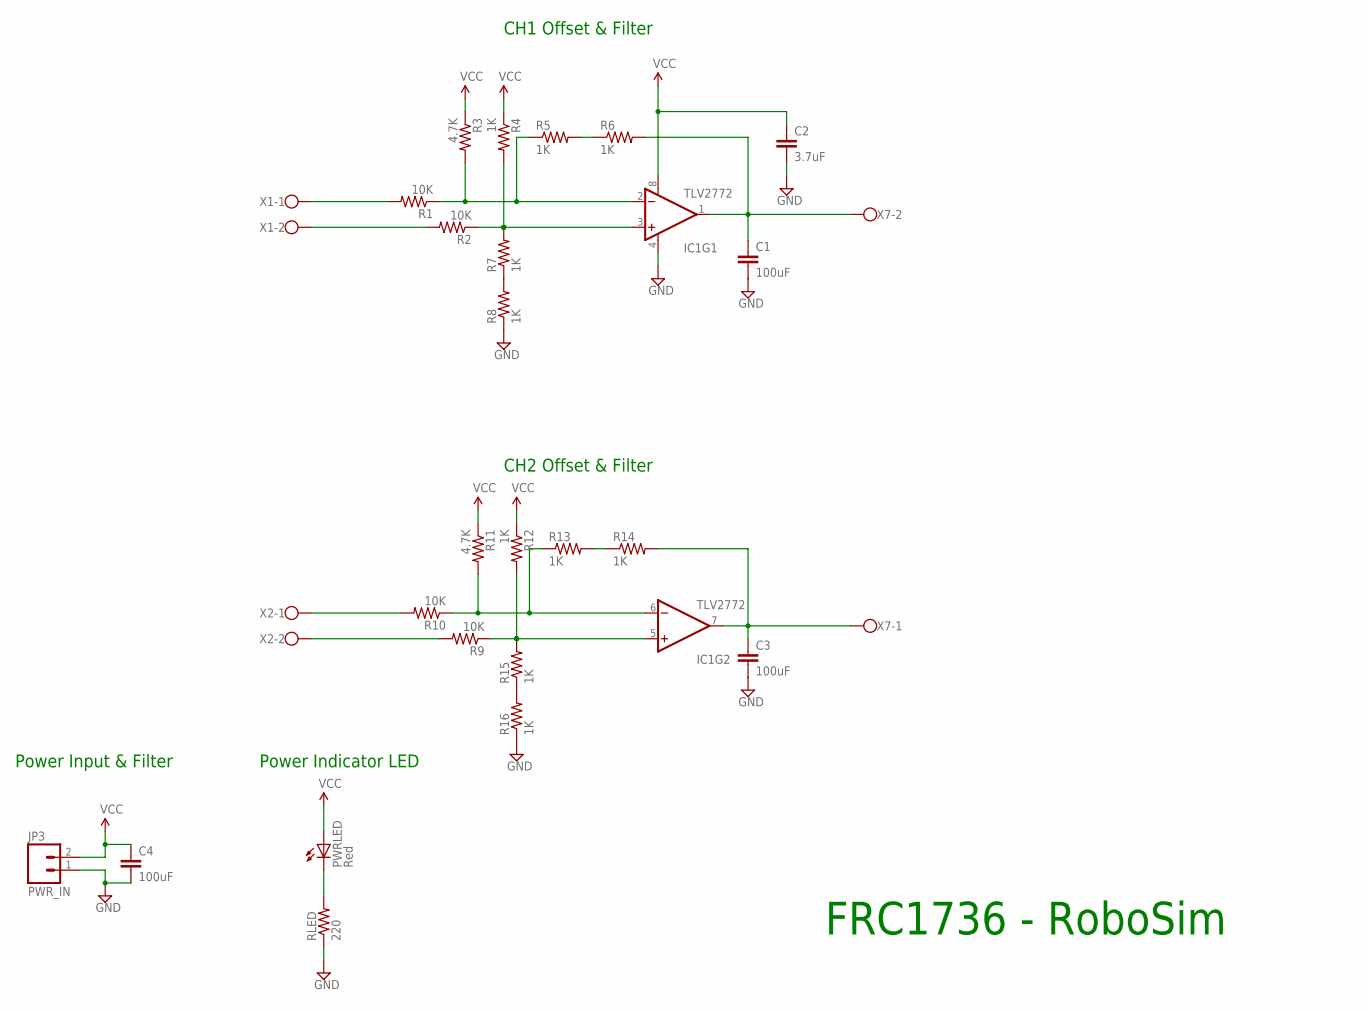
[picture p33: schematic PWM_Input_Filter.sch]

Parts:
C1, C3, C4: 100uF; CAP-PTH-SMALL
C2: 3.7uF; CAP-PTH-SMALL
IC1: TLV2772; DIP08
JP3: PWR_IN; 1X02_LOCK
PWRLED: Red; LED5MM
R1, R2, R9, R10: 10K; AXIAL-0.3
R3, R11: 4.7K; AXIAL-0.3
R4, R5, R6, R7, R8, R12, R13, R14, R15, R16: 1K; AXIAL-0.3
RLED: 220; AXIAL-0.3
X1, X2, X7: W237-102

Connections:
GND: C1.2, C2.2, C3.2, C4.2, IC1.4 (V-), JP3.1, R8.P$1 (1), R16.P$1 (1), RLED.P$1 (1)
unnamed: R1.P$2 (2), X1.1
unnamed: R9.P$2 (2), X2.2
unnamed: PWRLED.K (C), RLED.P$2 (2)
unnamed: IC1.2 (-IN), R1.P$1 (1), R3.P$2 (2), R5.P$1 (1)
unnamed: IC1.3 (+IN), R2.P$1 (1), R4.P$2 (2), R7.P$2 (2)
unnamed: R2.P$2 (2), X1.2
unnamed: R5.P$2 (2), R6.P$1 (1)
unnamed: R7.P$1 (1), R8.P$2 (2)
unnamed: IC1.6 (-IN), R10.P$1 (1), R11.P$2 (2), R13.P$1 (1)
unnamed: IC1.5 (+IN), R9.P$1 (1), R12.P$2 (2), R15.P$2 (2)
unnamed: C3.1, IC1.7 (OUT), R14.P$2 (2), X7.1
unnamed: R10.P$2 (2), X2.1
unnamed: R13.P$2 (2), R14.P$1 (1)
unnamed: R15.P$1 (1), R16.P$2 (2)
unnamed: C1.1, IC1.1 (OUT), R6.P$2 (2), X7.2
VCC: C2.1, C4.1, IC1.8 (V+), JP3.2, PWRLED.A, R3.P$1 (1), R4.P$1 (1), R11.P$1 (1), R12.P$1 (1)

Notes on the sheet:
Power Input & Filter
Power Indicator LED
CH1 Offset & Filter
CH2 Offset & Filter
FRC1736 - RoboSim

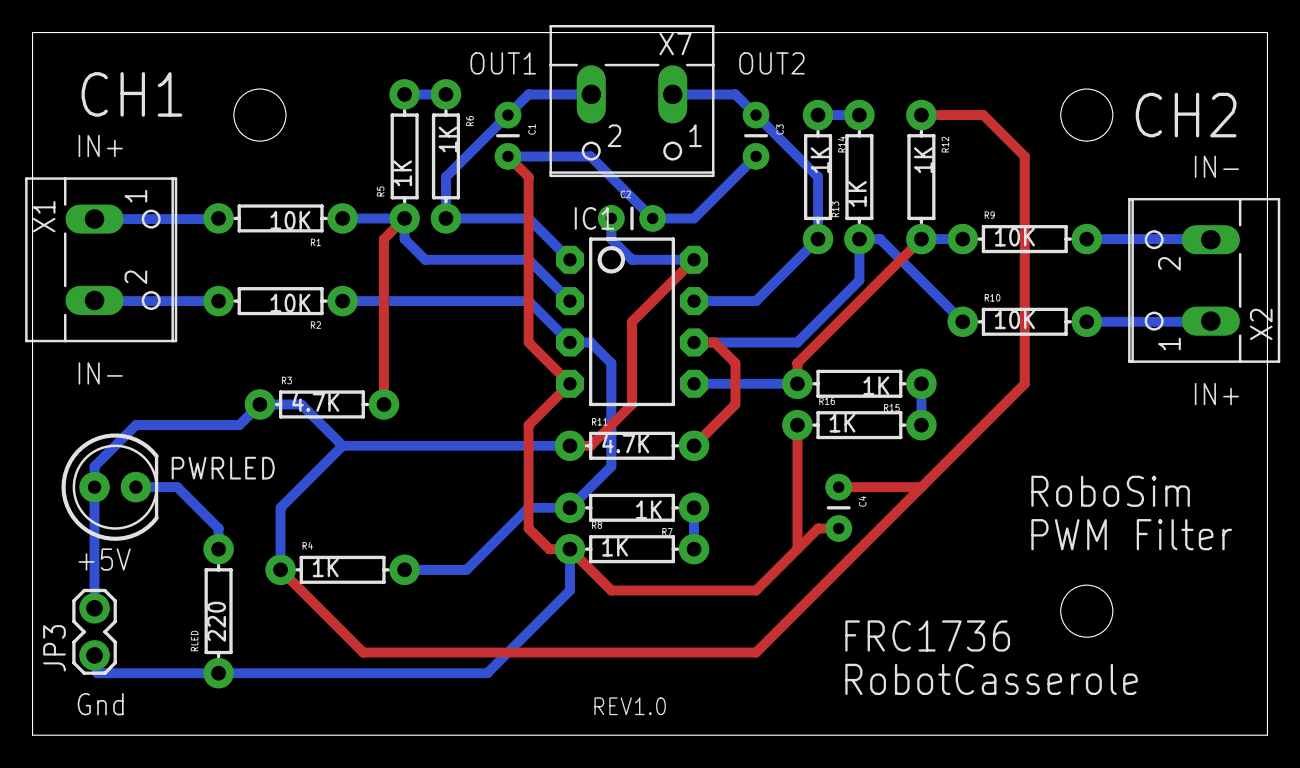
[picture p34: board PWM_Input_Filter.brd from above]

Board: 2 copper layers, 75.9 x 43.2 mm, 27 parts (0 on the bottom side), 17 nets.

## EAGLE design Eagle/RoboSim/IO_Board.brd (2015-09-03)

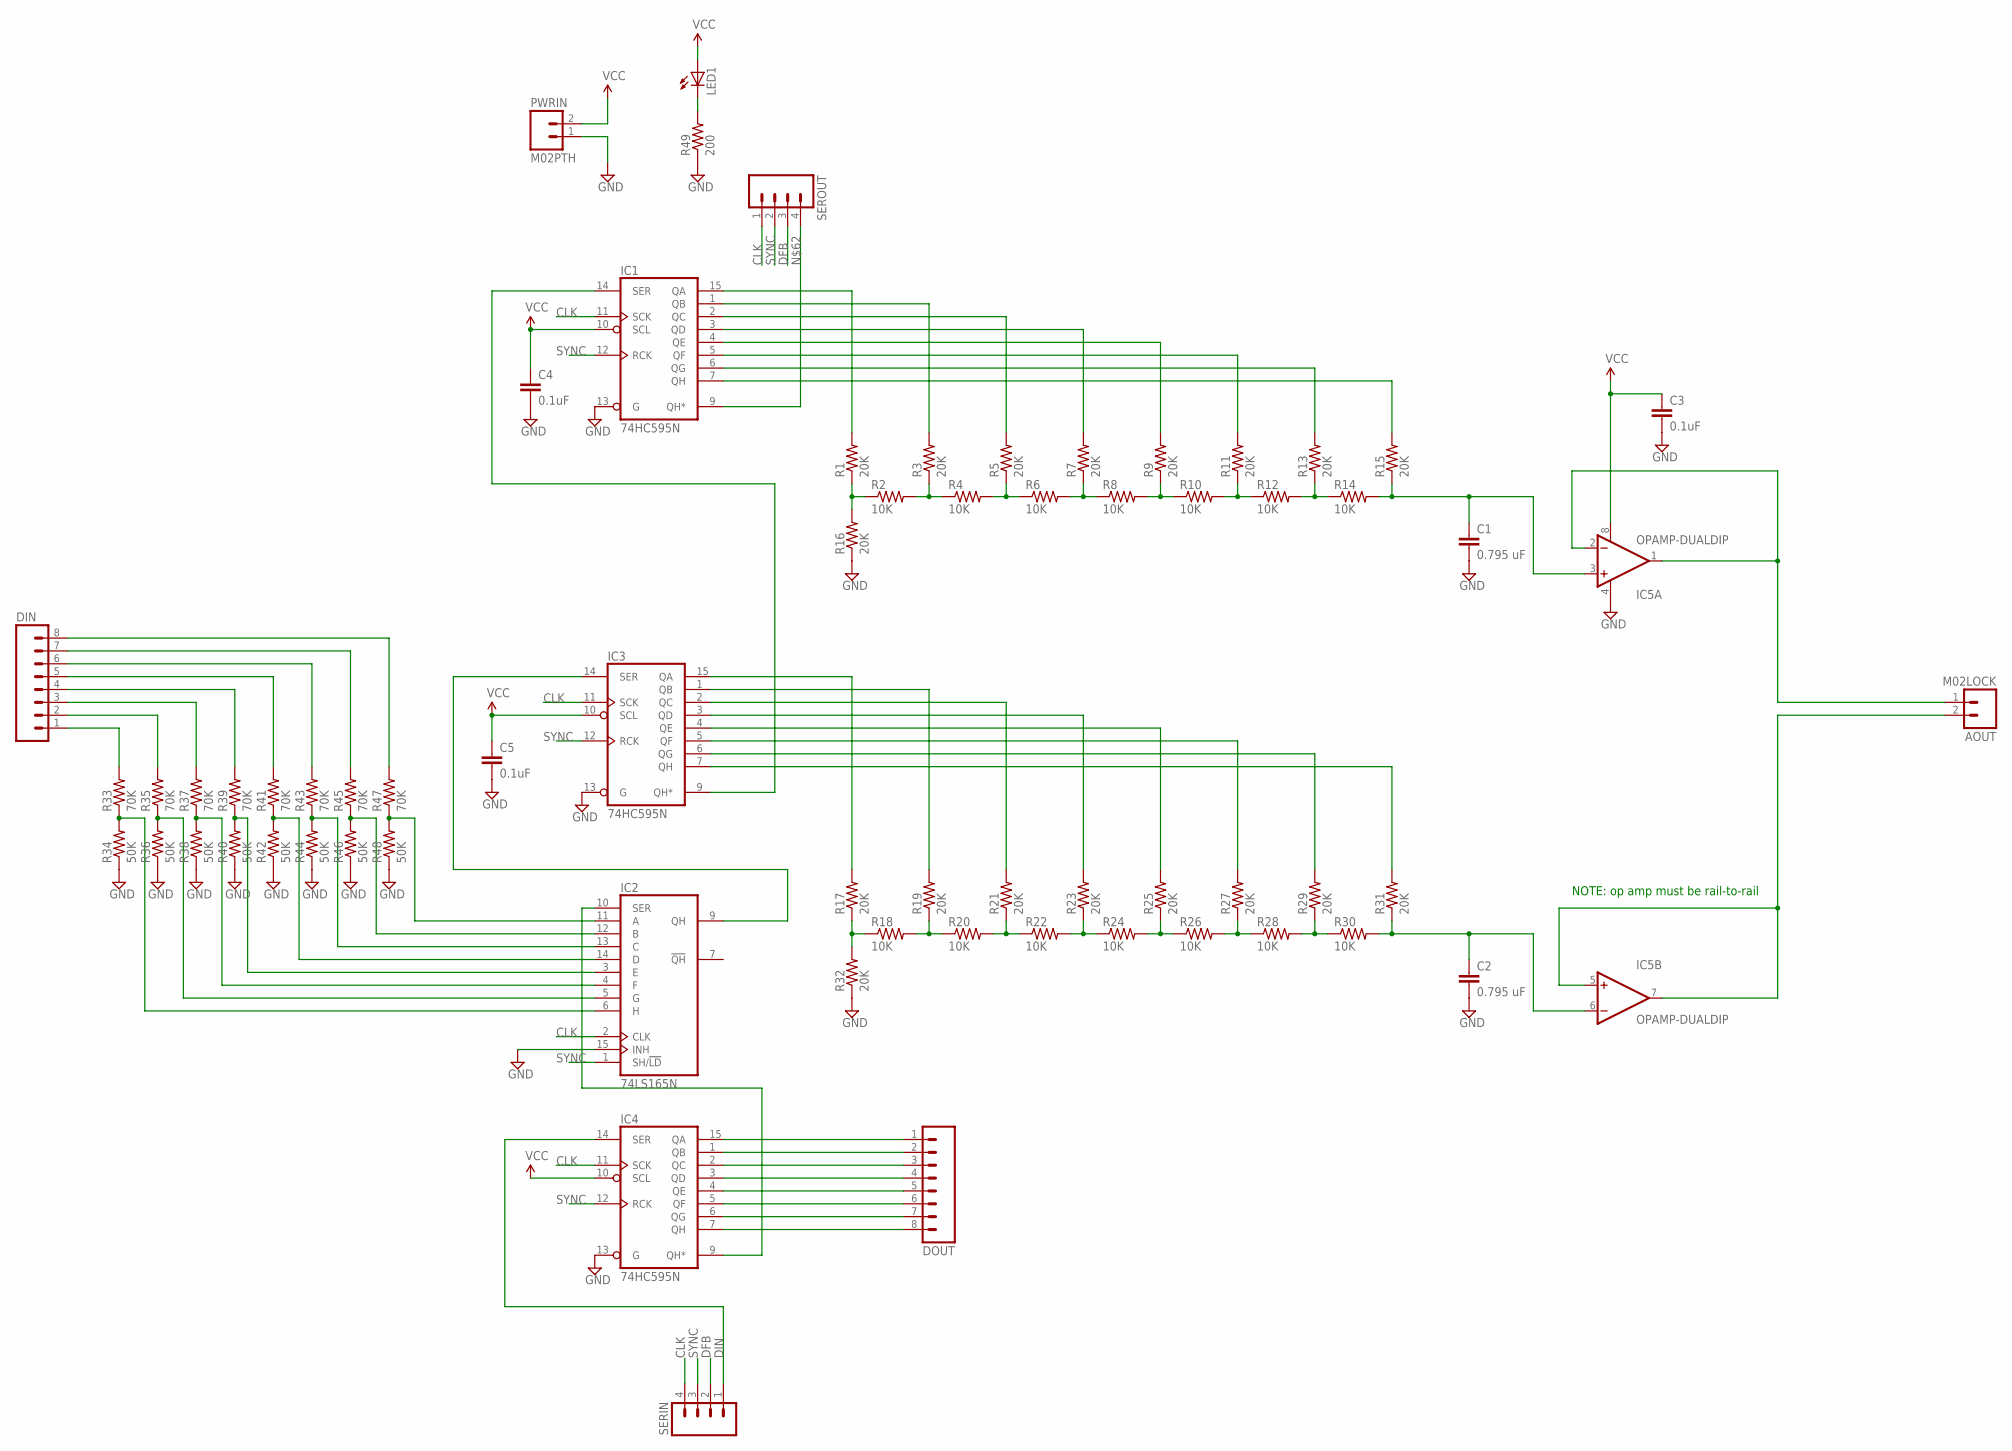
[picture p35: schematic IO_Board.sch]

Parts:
AOUT: M02LOCK; 1X02_LOCK
C1, C2: 0.795 uF; CAP-PTH-SMALL
C3, C4, C5: 0.1uF; CAP-PTH-SMALL
DIN: M08LOCK; 1X08_LOCK
DOUT: M08LOCK; 1X08_LOCK
IC1, IC3, IC4: 74HC595N; DIL16
IC2: 74LS165N; DIL16
IC5: OPAMP-DUALDIP; DIP08
LED1: LED5MM
PWRIN: M02PTH; 1X02
R1, R3, R5, R7, R9, R11, R13, R15, R16, R17, R19, R21, R23, R25, R27, R29, R31, R32: 20K; AXIAL-0.1
R2, R4, R6, R8, R10, R12, R14, R18, R20, R22, R24, R26, R28, R30: 10K; AXIAL-0.1
R33, R35, R37, R39, R41, R43, R45, R47: 70K; AXIAL-0.1
R34, R36, R38, R40, R42, R44, R46, R48: 50K; AXIAL-0.1
R49: 200; AXIAL-0.1
SERIN: M04LOCK; 1X04_LOCK
SEROUT: M04LOCK; 1X04_LOCK

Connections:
CLK: IC1.11 (SCK), IC2.2 (CLK), IC3.11 (SCK), IC4.11 (SCK), SERIN.4, SEROUT.1
DFB: SERIN.2, SEROUT.3
DIN: IC4.14 (SER), SERIN.1
GND: C1.2, C2.2, C3.2, C4.2, C5.2, IC1.8 (GND), IC1.13 (G), IC2.8 (GND), IC2.15 (INH), IC3.8 (GND), IC3.13 (G), IC4.8 (GND), IC4.13 (G), IC5.4 (V-), PWRIN.1, R16.P$1 (1), R32.P$1 (1), R34.P$1 (1), R36.P$1 (1), R38.P$1 (1), R40.P$1 (1), R42.P$1 (1), R44.P$1 (1), R46.P$1 (1), R48.P$1 (1), R49.P$1 (1)
unnamed: IC1.7 (QH), R15.P$2 (2)
unnamed: AOUT.2, IC5.5 (+IN), IC5.7 (OUT)
unnamed: IC1.6 (QG), R13.P$2 (2)
unnamed: IC1.5 (QF), R11.P$2 (2)
unnamed: IC1.4 (QE), R9.P$2 (2)
unnamed: IC1.3 (QD), R7.P$2 (2)
unnamed: IC1.2 (QC), R5.P$2 (2)
unnamed: IC1.1 (QB), R3.P$2 (2)
unnamed: IC1.15 (QA), R1.P$2 (2)
unnamed: R1.P$1 (1), R2.P$1 (1), R16.P$2 (2)
unnamed: R2.P$2 (2), R3.P$1 (1), R4.P$1 (1)
unnamed: R4.P$2 (2), R5.P$1 (1), R6.P$1 (1)
unnamed: R6.P$2 (2), R7.P$1 (1), R8.P$1 (1)
unnamed: R8.P$2 (2), R9.P$1 (1), R10.P$1 (1)
unnamed: R10.P$2 (2), R11.P$1 (1), R12.P$1 (1)
unnamed: R12.P$2 (2), R13.P$1 (1), R14.P$1 (1)
unnamed: C1.1, IC5.3 (+IN), R14.P$2 (2), R15.P$1 (1)
unnamed: AOUT.1, IC5.1 (OUT), IC5.2 (-IN)
unnamed: IC3.7 (QH), R31.P$2 (2)
unnamed: IC3.6 (QG), R29.P$2 (2)
unnamed: IC3.5 (QF), R27.P$2 (2)
unnamed: IC3.4 (QE), R25.P$2 (2)
unnamed: IC3.3 (QD), R23.P$2 (2)
unnamed: IC3.2 (QC), R21.P$2 (2)
unnamed: IC3.1 (QB), R19.P$2 (2)
unnamed: IC3.15 (QA), R17.P$2 (2)
unnamed: R17.P$1 (1), R18.P$1 (1), R32.P$2 (2)
unnamed: R18.P$2 (2), R19.P$1 (1), R20.P$1 (1)
unnamed: R20.P$2 (2), R21.P$1 (1), R22.P$1 (1)
unnamed: R22.P$2 (2), R23.P$1 (1), R24.P$1 (1)
unnamed: R24.P$2 (2), R25.P$1 (1), R26.P$1 (1)
unnamed: R26.P$2 (2), R27.P$1 (1), R28.P$1 (1)
unnamed: R28.P$2 (2), R29.P$1 (1), R30.P$1 (1)
unnamed: C2.1, IC5.6 (-IN), R30.P$2 (2), R31.P$1 (1)
unnamed: IC2.6 (H), R33.P$1 (1), R34.P$2 (2)
unnamed: IC2.5 (G), R35.P$1 (1), R36.P$2 (2)
unnamed: IC2.4 (F), R37.P$1 (1), R38.P$2 (2)
unnamed: IC2.3 (E), R39.P$1 (1), R40.P$2 (2)
unnamed: IC2.14 (D), R41.P$1 (1), R42.P$2 (2)
unnamed: IC2.13 (C), R43.P$1 (1), R44.P$2 (2)
unnamed: IC2.12 (B), R45.P$1 (1), R46.P$2 (2)
unnamed: IC2.11 (A), R47.P$1 (1), R48.P$2 (2)
unnamed: DOUT.1, IC4.15 (QA)
unnamed: DOUT.2, IC4.1 (QB)
unnamed: DOUT.3, IC4.2 (QC)
unnamed: DOUT.4, IC4.3 (QD)
unnamed: DOUT.5, IC4.4 (QE)
unnamed: DOUT.6, IC4.5 (QF)
unnamed: DOUT.7, IC4.6 (QG)
unnamed: DOUT.8, IC4.7 (QH)
unnamed: DIN.8, R47.P$2 (2)
unnamed: DIN.7, R45.P$2 (2)
unnamed: DIN.6, R43.P$2 (2)
unnamed: DIN.5, R41.P$2 (2)
unnamed: DIN.4, R39.P$2 (2)
unnamed: DIN.3, R37.P$2 (2)
unnamed: DIN.2, R35.P$2 (2)
unnamed: DIN.1, R33.P$2 (2)
unnamed: IC2.9 (QH), IC3.14 (SER)
unnamed: LED1.K (C), R49.P$2 (2)
unnamed: IC1.9 (QH*), SEROUT.4
unnamed: IC1.14 (SER), IC3.9 (QH*)
SYNC: IC1.12 (RCK), IC2.1 (SH/!LD), IC3.12 (RCK), IC4.12 (RCK), SERIN.3, SEROUT.2
VCC: C3.1, C4.1, C5.1, IC1.10 (SCL), IC1.16 (VCC), IC2.16 (VCC), IC3.10 (SCL), IC3.16 (VCC), IC4.10 (SCL), IC4.16 (VCC), IC5.8 (V+), LED1.A, PWRIN.2

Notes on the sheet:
NOTE: op amp must be rail-to-rail

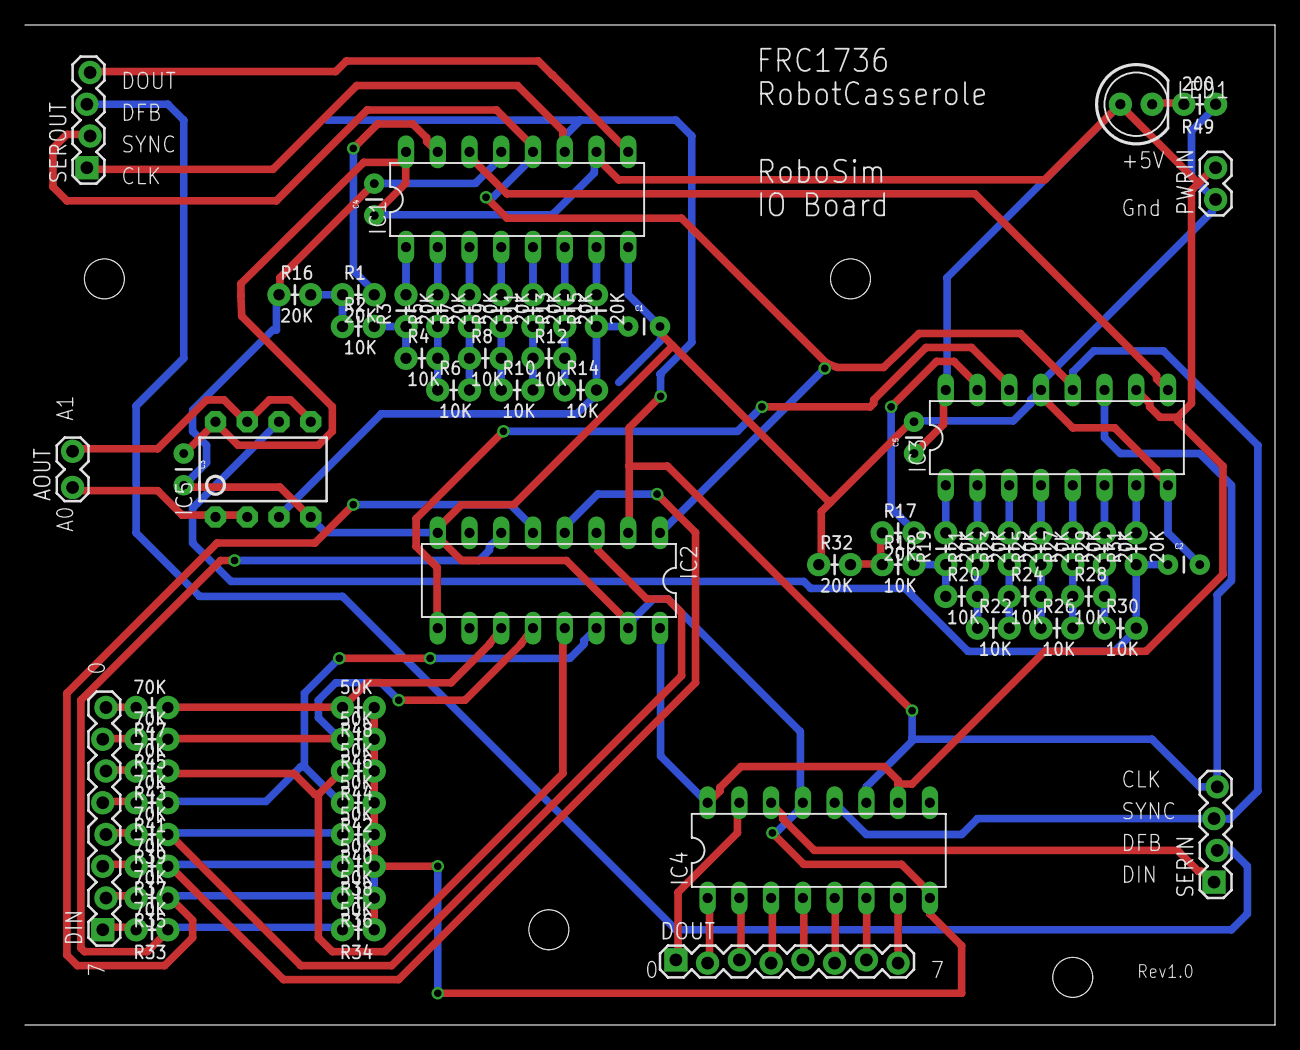
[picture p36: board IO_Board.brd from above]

Board: 2 copper layers, 100.0 x 80.0 mm, 66 parts (0 on the bottom side), 68 nets.

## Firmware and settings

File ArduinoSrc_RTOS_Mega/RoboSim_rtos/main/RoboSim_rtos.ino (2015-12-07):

/******************************************************************************/
/******************************************************************************/
/**   COPYRIGHT (C) FRC TEAM 1736 ROBOT CASSEROLE 2015 ALL RIGHTS RESERVED   **/
/******************************************************************************/
/******************************************************************************/
// RoboSim - an Arduino-based, Hardware-in-the-loop Robot simulation platform
//
// File: RoboSim.ino
// Description:  - Main entry functions for Arduino
//               - Performs all setup actions and contains main control loop
//
//  Change History:
//      Chris Gerth - 20Mar2015 - Created
//
/******************************************************************************/

/******************************************************************************/
/** HEADER INCLUDES                                                          **/
/******************************************************************************/
#include "hardwareInterface.h"
#include "plant.h"
#include "display.h"
#include "FreeRTOS_AVR.h"

//#define ENABLE_TASK_DEBUG_PRINT

/******************************************************************************/
/** DATA DEFINITIONS                                                         **/
/******************************************************************************/


/******************************************************************************/
/** FUNCTIONS                                                                **/
/******************************************************************************/

////////////////////////////////////////////////////////////////////////////////
// static void vPCSerialTx()
// Description: RTOS Task for transmitting serial packets to the PC
//
//
// Input Arguments: pvParameters - not used
// Returns: None
////////////////////////////////////////////////////////////////////////////////
static void vPCSerialTx(void *pvParameters) {
  TickType_t xLastWakeTime;
  const TickType_t xFrequency = (TickType_t)round(SERIAL_TX_TASK_RATES_S * ((double)configTICK_RATE_HZ)); //calculate number of RTOS scheduler ticks to wait 
  xLastWakeTime = xTaskGetTickCount();

  #ifdef ENABLE_TASK_DEBUG_PRINT
  Serial.println("Done Initalizing TX Task");
  Serial.flush();
  #endif 
  
  
  for(;;)
  {
    vTaskDelayUntil( &xLastWakeTime, xFrequency );
    //send packet back to PC
    send_packet_to_pc();
    #ifdef ENABLE_TASK_DEBUG_PRINT
    Serial.println("Finished loop of Tx");
    Serial.flush();
    #endif 
  }
}

////////////////////////////////////////////////////////////////////////////////
// static void vPCSerialRx()
// Description: RTOS Task for recieving serial packets from the PC
//
//
// Input Arguments: pvParameters - not used
// Returns: None
////////////////////////////////////////////////////////////////////////////////
static void vPCSerialRx(void *pvParameters) {
  TickType_t xLastWakeTime;
  const TickType_t xFrequency = (TickType_t)round(SERIAL_RX_TASK_RATES_S * ((double)configTICK_RATE_HZ)); //calculate number of RTOS scheduler ticks to wait 
  xLastWakeTime = xTaskGetTickCount();
  
  #ifdef ENABLE_TASK_DEBUG_PRINT
  Serial.println("Done Initalizing RX Task");
  Serial.flush();
  #endif 
  
  for(;;)
  {
    //recieve packet ("blocking", but let RTOS run in background)
    //TODO: This way of doing it is clunky. This is bad coding practice, because
    // it cannot be statically determined that this while loop will ever exit.
    // Additionally, this yeilding is what the scheduler should be doing, not us.
    // Preferred method would be to just attempt to get the packet, and do nothing if
    // there's not packet available. WIll require testing to ensure that's possible,
    // and doesn't hose up any other functionality.
    vTaskDelayUntil( &xLastWakeTime, xFrequency );
    while(get_packet_from_pc() == -1)
    {
        vTaskDelayUntil( &xLastWakeTime, 1);
    } 
    #ifdef ENABLE_TASK_DEBUG_PRINT
    Serial.println("Finished loop of Rx");
    Serial.flush();
    #endif 
  }
}

////////////////////////////////////////////////////////////////////////////////
// static void vHWIOSample()
// Description: RTOS Task for sampling hardware inputs, and setting 
//              hardware outputs
//
//
// Input Arguments: pvParameters - not used
// Returns: None
////////////////////////////////////////////////////////////////////////////////
static void vHWIOSample(void *pvParameters) {
  TickType_t xLastWakeTime;
  const TickType_t xFrequency = (TickType_t)round(HW_IO_SAMPLE_TASK_RATES_S * ((double)configTICK_RATE_HZ)); //calculate number of RTOS scheduler ticks to wait   
  xLastWakeTime = xTaskGetTickCount();
  
  #ifdef ENABLE_TASK_DEBUG_PRINT
  Serial.println("done initializing hwiosample");
  Serial.flush();
  #endif
  
  for(;;)
  {
    vTaskDelayUntil( &xLastWakeTime, xFrequency );
    //Acquire input & set output
    //these functions will write values to global variables
    sample_motor_values(); //motor vals - input only
    io_card_exchange_data(); // IO card - input and output
    #ifdef ENABLE_TASK_DEBUG_PRINT
    Serial.println("Finished loop of HWIO sample");
    Serial.flush();
    #endif
  }
}

////////////////////////////////////////////////////////////////////////////////
// static void vPlantRunLoop() 
// Description: RTOS task for executing an on-arduino plant model
//
//
// Input Arguments: pvParameters - not used
// Returns: None
////////////////////////////////////////////////////////////////////////////////
static void vPlantRunLoop(void *pvParameters) {
  TickType_t xLastWakeTime;
  const TickType_t xFrequency = (TickType_t)round(PLANT_LOOP_TASK_RATES_S * ((double)configTICK_RATE_HZ)); //calculate number of RTOS scheduler ticks to wait   
  xLastWakeTime = xTaskGetTickCount();
  #ifdef ENABLE_TASK_DEBUG_PRINT
  Serial.println("done initalizing plant task");
  Serial.flush();
  #endif 
  for(;;)
  {
    vTaskDelayUntil( &xLastWakeTime, xFrequency );
    //run plant model
    plant_periodic_loop();
  }
  #ifdef ENABLE_TASK_DEBUG_PRINT
  Serial.println("Finished loop of Plant");
  Serial.flush();
  #endif 
}

////////////////////////////////////////////////////////////////////////////////
// static void vDisplayUpdate()
// Description: RTOS task for updating content displayed on the OLED display
//
//
// Input Arguments: pvParameters - not used
// Returns: None
////////////////////////////////////////////////////////////////////////////////
static void vDisplayUpdate(void *pvParameters) {
  TickType_t xLastWakeTime;
  const TickType_t xFrequency = (TickType_t)round(DISPLAY_UPDATE_TASK_RATES_S * ((double)configTICK_RATE_HZ)); //calculate number of RTOS scheduler ticks to wait   
  xLastWakeTime = xTaskGetTickCount();
  #ifdef ENABLE_TASK_DEBUG_PRINT
  Serial.println("done initalizing display update task");
  Serial.flush();
  #endif 
  for(;;)
  {
    vTaskDelayUntil( &xLastWakeTime, xFrequency );
    //Update display
    display_calc_screen_index();
    display_update();
  }
  #ifdef ENABLE_TASK_DEBUG_PRINT
  Serial.println("Finished loop of display update");
  Serial.flush();
  #endif 
}


////////////////////////////////////////////////////////////////////////////////
// void setup() 
// Description: Initalize function required by arduino. Main entry point of the
//              SW after bootloader hands off execution control to user software.
//
// Input Arguments: None
// Returns: None
////////////////////////////////////////////////////////////////////////////////
void setup()
{
    // WHEN POWER IS APPLIED TO THE ARDUINO OR THE RESET BUTTON IS PRESSED,
    // THE SW EXECUTION STARTS RIGHT HERE!!!
    
    //init display
    display_init();
    display_boot_screen();
      
    //Open Serial port
    Serial.begin(115200, SERIAL_8E2); //config to 115200 baud, 8 data bits, even parity, 2 stop bits
    
    //start up encoders
    encoderInit();
    
    //start up motor inputs
    init_motor_inputs();
    
    //set up io cards
    init_io_card();
    
    #ifdef ENABLE_TASK_DEBUG_PRINT
    Serial.println("done with init");
    Serial.flush();
    #endif
    
    //set up rtos tasks (initalize data structures and stacks for them)
    // This will NOT start running them (yet), just defines what they should be.
    //Priorities go from tskIdle_Priority to configMAX_PRIORITIES
    //empirically determined stack sizes seems to be the minimum stack size usable
    //Only create a task if it is enabled.
    if(HW_IO_SAMPLE_TASK_ENABLE)
    {
        xTaskCreate(vHWIOSample, "HWIO", 350 , NULL, tskIDLE_PRIORITY + 10, NULL);
        #ifdef ENABLE_TASK_DEBUG_PRINT
        Serial.println("created HWIOSample task");
        Serial.flush();
        #endif
    }
    if(SERIAL_TX_TASK_ENABLE)
    {
        xTaskCreate(vPCSerialTx, "SerTx", 300, NULL, tskIDLE_PRIORITY + 8, NULL);
        #ifdef ENABLE_TASK_DEBUG_PRINT
        Serial.println("created tx task");
        Serial.flush();
        #endif
    }
    if(SERIAL_RX_TASK_ENABLE)
    {
        xTaskCreate(vPCSerialRx, "SerRx", 300, NULL, tskIDLE_PRIORITY + 6, NULL);
        #ifdef ENABLE_TASK_DEBUG_PRINT
        Serial.println("created rx task");
        Serial.flush();
        #endif
    }
    if(DISPLAY_UPDATE_TASK_ENABLE)
    {
        xTaskCreate(vDisplayUpdate, "DispUpd", 500, NULL, tskIDLE_PRIORITY + 2, NULL);
        #ifdef ENABLE_TASK_DEBUG_PRINT
        Serial.println("created display update task");
        Serial.flush();
        #endif
    }
    if(PLANT_LOOP_TASK_ENABLE)
    {
        xTaskCreate(vPlantRunLoop, "PlantMdl", 500, NULL, tskIDLE_PRIORITY + 7, NULL);
        #ifdef ENABLE_TASK_DEBUG_PRINT
        Serial.println("created plant model update task");
        Serial.flush();
        #endif
    }
    
    
    
    // start RTOS
    #ifdef ENABLE_TASK_DEBUG_PRINT
    Serial.println("Starting Scheduler");
    Serial.flush();
    #endif
    vTaskStartScheduler();
    
    // Above function should never return
    // If it does, just hang out, I guess...
    while(1);
    //TODO: more robust thing could be to reset the system at this point?
    
}



////////////////////////////////////////////////////////////////////////////////
// void loop() 
// Description: minimal idle task loop
// it's got a tiny stack, so don't do anything here!!! :o
//
////////////////////////////////////////////////////////////////////////////////
void loop()
{
  while(1);
}

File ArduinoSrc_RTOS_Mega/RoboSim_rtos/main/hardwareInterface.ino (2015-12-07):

/******************************************************************************/
/******************************************************************************/
/**   COPYRIGHT (C) FRC TEAM 1736 ROBOT CASSEROLE 2015 ALL RIGHTS RESERVED   **/
/******************************************************************************/
/******************************************************************************/
// RoboSim - an Arduino-based, Hardware-in-the-loop Robot simulation platform
//
// File: hardwareInterface.cpp
// Description:  - Interface functions relevant to the interfacing of
//                 the arduino to the hardware inside the sim box.
//
//  Change History:
//      Chris Gerth - 20Mar2015 - Created
//
/******************************************************************************/


/******************************************************************************/
/** HEADER INCLUDES                                                          **/
/******************************************************************************/

#include "hardwareInterface.h"

/******************************************************************************/
/** DATA DEFINITIONS                                                         **/
/******************************************************************************/
volatile unsigned long encoder_periods[NUM_ENCODER_OUTPUTS];
volatile unsigned long encoder_state_timers[NUM_ENCODER_OUTPUTS];
volatile char encoder_states[NUM_ENCODER_OUTPUTS];
volatile char encoder_directions[NUM_ENCODER_OUTPUTS];
volatile char encoder_enabled[NUM_ENCODER_OUTPUTS];
int motor_input_readings[NUM_MOTOR_INPUTS];
bool digital_inputs[NUM_IO_CARDS*8];
bool digital_outputs[NUM_IO_CARDS*8];
double analog_outputs[NUM_IO_CARDS*2];
bool pc_connected = 0;
long rx_packet_count = 0;
long tx_packet_count = 0;

/******************************************************************************/
/** FUNCTIONS                                                                **/
/******************************************************************************/

////////////////////////////////////////////////////////////////////////////////
// void set_encoder_period_ms() 
// Description: Takes a period length in ms and and sets the encoder outputs
//
// Input Arguments: double - period of the pwm wave in ms
//                  bool - direction of the encoder's travel. ENCODER_DIR_FWD or ENCODER_DIR_BKD.
//                  char - encoder number to change output of
// Returns: None
// Globals Written: Encoder globals
////////////////////////////////////////////////////////////////////////////////
void set_encoder_period_ms( double encoder_period_ms_in, char encoder_num)
{ 
  //case, encoder stopped
  if(encoder_period_ms_in > MAX_PWM_PERIOD_MS | encoder_period_ms_in < -MAX_PWM_PERIOD_MS)
  {
    encoder_periods[encoder_num] = 0;
    encoder_enabled[encoder_num] = false;
  }
  //case, encoder running forward
  else if(encoder_period_ms_in > 0)
  {
    encoder_periods[encoder_num] = (unsigned long)round(encoder_period_ms_in / 4.0 / (double)ENCODER_INT_PERIOD_MS);
    encoder_enabled[encoder_num] = true;
    encoder_directions[encoder_num] = ENCODER_DIR_FWD;
  }
  //case, encoder running backward
  else
  {
    encoder_periods[encoder_num] = (unsigned long)round(-encoder_period_ms_in / 4.0 / (double)ENCODER_INT_PERIOD_MS);
    encoder_enabled[encoder_num] = true;
    encoder_directions[encoder_num] = ENCODER_DIR_BKD;
  }
  
}

////////////////////////////////////////////////////////////////////////////////
// double get_motor_in_voltage
// Description: Takes a motor number, and returns the most recent voltage read
//
// Input Arguments: char - motor number to get input from
//                  
// Output: Motor voltage
// Globals Read: motor_input_readings
////////////////////////////////////////////////////////////////////////////////
double get_motor_in_voltage(char motor_num)
{
  //run motor value through five point map
  return five_point_map(motor_input_readings[motor_num],input_map[motor_num],output_map);
}

////////////////////////////////////////////////////////////////////////////////
// void sample_motor_values
// Description: Reads and saves analog port values for motor voltages
//
// Input Arguments: none
//                  
// Returns: None
// Globals Written: motor_input_readings
////////////////////////////////////////////////////////////////////////////////
void sample_motor_values()
{
  int i;
  for(i = 0; i<NUM_MOTOR_INPUTS; i++)
  {
    motor_input_readings[i] = analogRead(motor_int_pin_numbers[i]);
  }
  
}
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

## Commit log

2015-03-24 initial content commit. Basic structure laid out, quadrature encoder emulation started
2015-03-24 work in progrss - encoder emulators generate output, but scaling is not yet correct
    [ISRs.ino, hardwareConfig.h, hardwareInterface.h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]
2015-03-26 confirmed timing logic, added main loop with 0.1s Ts, started analog reads for motors
2015-03-28 added input PWM filter pspice simulation, schematic, and board files
    [PWM_Input_Filter.brd, PWM_Input_Filter.sch]
2015-03-28 added hw led flash and analog reads and plant skeleton function
2015-03-29 Added IO board schematic and board
    [IO_Board.brd, IO_Board.sch]
2015-04-03 finished writieng code for IO board. need to validate code and add more comments
2015-05-01 updated op amp part number
    [PWM_Input_Filter.brd, PWM_Input_Filter.sch]
2015-05-21 Corrected sync signal behavor, still need to test on board
    [hardwareConfig.h, hardwareInterface.ino]
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2015-05-29 updated wiring diagram for DAC's. added fast io functions to arduino code. Added test vector generation. Still tuning good compromise between signal fedility and processor load
    [IO_Board.brd, IO_Board.sch]
2015-06-11 Fixed issue with ch1 analog voltage follower. confirmed full board functionality
    [IO_Board.brd]
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2015-06-26 actually fixed input circuit
2015-07-02 Updated pwm input filter schematic
    [PWM_Input_Filter.brd, PWM_Input_Filter.sch]
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2015-07-13 updated motor model with actual numbers. Isn't 100% accurate, especially with steady-state speed under no load...
2015-07-17 Updated readmes, removed GUI/ since it's no longer needed
    [arduino_serial_tx_test.ino]
2015-07-17 fixed file names to not be silly. SCREAMING_SNAKE_CASE is for silly developers.
    [ISRs.ino, arduino_serial_tx_test.ino, hardwareConfig.h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]
2015-07-20 Work-in-progress on setting up octave plant model to work with arduino. Need to still adjust quad encoder setup to read period commands (in ms) from PC, and actually write serial packet send/recieve 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
2015-07-20 added serial tx/rx functions to arduino code, fleshed out definition of packet in octave plant comments. Still untested, though.
2015-07-20 added serial data packet send/recieve functions to roboSim arduino
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2015-07-22 added gui inputs for encoder outputs. Tested serial send loop
2015-07-22 continued gui work. still need to put together packet assembly and read code, and GUI outputs for recieved packets
2015-08-05 Updated to print malloc usage optionally, reduced idle task function call depth
2015-08-19 Reduced digital pulse time and added interrupt disable around each io card byte transmit. Haven't verified this didnt' break anything yet, although it looks good for now.
2015-08-21 updated circuit 1 on the board to proper experimented values. Need to update the others as well
    [PWM_Input_Filter.brd, PWM_Input_Filter.sch]
2015-08-21 updated resistor values and op-amp configuration
    [PWM_Input_Filter.brd, PWM_Input_Filter.sch]
2015-08-22 changed pins to screw terminals and made resistors surface mount. Still need to position components and route
    [PWM_Input_Filter.brd, PWM_Input_Filter.sch]
2015-08-22 trimmed pwm filter circuit schematic to just show two channels, fixed up schematic
    [PWM_Input_Filter.brd, PWM_Input_Filter.sch]
2015-08-22 added extra text to schematic
    [PWM_Input_Filter.brd, PWM_Input_Filter.sch]
2015-08-22 moved pwm filter's brd annotation layers again so they'd show up on the board silkscreen
    [PWM_Input_Filter.brd]
2015-08-22 updated io board schematic, both PCB's ready for production
    [IO_Board.brd, IO_Board.sch]
2015-08-25 Added enclosure
    [10 PORT HEADER.ipt, 102 RESISTOR PACK.ipt, 103 RESISTOR PACK.ipt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]
2015-08-25 started making panel parts from enclosure
    [base.0002.ipt, base.ipt, front.0002.ipt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]
2015-08-26 Finished parted-out enclosure CAD, added mounting holes and chef hat to pcb's
    [IO_Board.brd, PWM_Input_Filter.brd, base.0002.ipt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]
2015-08-28 cleaned up Eagle folder, corrected CH2 label (wrong layer)
    [PWM_Input_Filter.brd]
2015-08-28 added inputs from robosim to test gui, tweaking timing. fixed lag, but get missed packets every now and then
    [RoboSim_rtos.ino]
2015-08-29 Fixed the serial read/write functionality to add checksum checker, and get around odd multi-byte read bug. Test gui seems to work perfectly now. Ran for like 20 minutes and no bad serial reads
    [RoboSim_rtos.ino, hardwareInterface.ino]
2015-09-05 added test for compressor&tank model. Tweaked values per Andymark's website. Their website still claims it can fill a 500mL tank to 120PSI in 13 seconds, but my model is taking closer to two minutes.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
2015-09-06 added pressure sensor model and simple pneumatic system test. Still need to tune cylinder values for realistic behavior.
2015-10-04 Copied arduino src and started working for arduino Mega. Added OLED display routines. Increasesd memory allocaions and added OS error print-to-OLED display handling
    [Adafruit_SSD1306.ino, ISRs.ino, RoboSim_rtos.ino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]
2015-10-04 Added memory usage tracking fcn. DOesn't look like it actually works. Perhaps we need to look at the RTOS...
    [display.ino, memory_monitor.ino]
2015-10-04 restructured arduino RTOS mega folder into actual folders, added python build utility
2015-10-04 added arduino exe and serial port autodetect to build script
2015-10-05 eliminated interrupt disable around io board read/write to increase accuracy of encoders. took extra debug info out of build.py. added encoder period screens to display
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2015-10-15 finished updates to cal values for motor inputs
2015-10-17 added top-level schematic. Adjusted output pin numbers
    [RoboSim_top_level.sch]
2015-10-28 added robot draw and field collision detection in 1D. Framework set for rotation calculations
2015-10-29 Getting closer... rotation and friction added. Still some odd behavior with motor speeds...
2015-10-31 Fixed math error in robot motor speed calculation
    Added "Config Calc" structure for robot to minimize re-calculation of constants every loop
    cleaned up some formatting
    adjusted robot and field physical params to match 2015 game closer.
2015-10-31 Added battery charge electrical model
    Pulled CIM motor model from common lib area
    Removed cloned CIM motor model
    Minor comment udpates
2015-10-31 Updated motor input voltages to be scaled by system voltage
    Minor testcase cleanup
2015-10-31 Added build options to python Arduino build script
    more robust board type detection
2015-11-01 Moved motor sim model back to standard lib/lib_test folders
2015-11-01 Fixed motor model. Confirmed current draw looks reasonable.
2015-11-05 Updated sample time to attempt a 50ms sample time. not sure if it works or not. maybe can go slower, maybe need faster?
2015-11-06 added some starts to the docs, still working on sample time
2015-11-11 removed lyx temp file. Corrected 5 pt map bug. Updated sample time to be 50ms. Some occasional missed sample points, but nothing major
    [display.ino, five_point_map.ino, hardwareConfig.h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]
2015-11-14 Aded drawing for sim robot
    [sim_model.dxf]
2015-11-14 updated analysis pdf and cleaned up code comments and format for arduino rtos. Need to test build.
2015-11-15 Fixed missing header in hwconfig.h, updated make utility to print a help message
    [hardwareConfig.h, make_RoboSim.py]
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2015-11-18 added start to drivetrain integrated model description. Still need electrical and pneumatic and field interactions

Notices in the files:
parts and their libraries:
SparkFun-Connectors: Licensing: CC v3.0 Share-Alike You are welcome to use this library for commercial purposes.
